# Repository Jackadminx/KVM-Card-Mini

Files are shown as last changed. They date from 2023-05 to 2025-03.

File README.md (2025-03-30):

# KVM-Card-Mini

⌨️🖥️🖱️

Simple KVM Console to USB 

[ENGLISH Version](https://github.com/Jackadminx/KVM-Card-Mini/blob/main/README-en.md)

一款即插即用的 KVM （Keyboard Video Mouse）设备控制卡

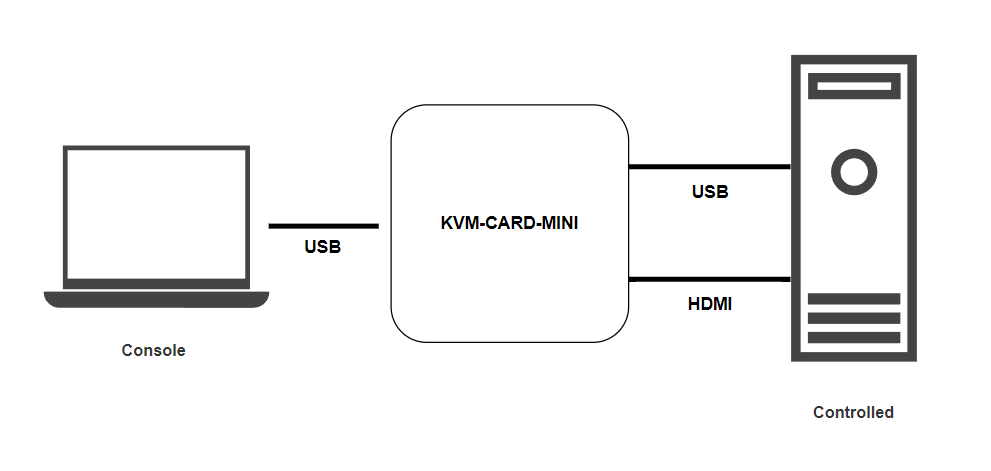
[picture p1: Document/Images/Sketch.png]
Sketch


## 功能特点

- HID 协议传输，免驱动，支持USB FS传输速度
- 支持 BIOS 键盘控制
- 上位机程序兼容非板载视频采集卡
- 板载 USB HUB 芯片，减少接口数量
- MCU 双 USB Device 控制器，降低传输延迟
- 板载蓝牙天线、调试接口，可用于MCU开发
- USB 设备主从切换

[演示视频](https://www.bilibili.com/video/BV1Mh4y1o7ya)

## 硬件分析

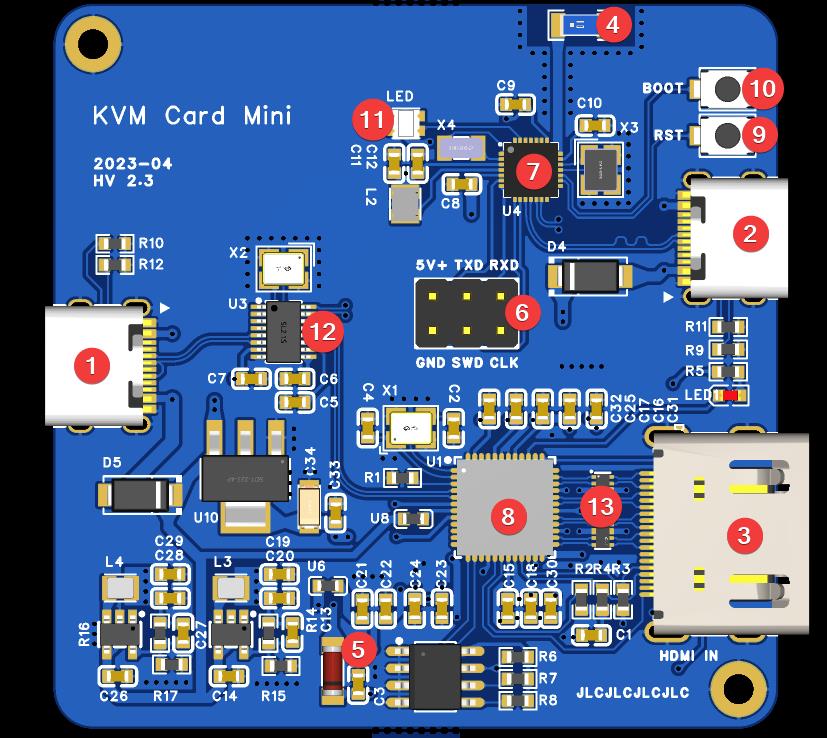
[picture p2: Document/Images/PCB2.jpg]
PCB


1. **（控制端）USB Host Type-C 接口，连接至上位机**
2. **（被控端）USB Host Type-C 接口，连接至被控端，控制键盘鼠标**
3. **（被控端）标准 HDMI 视频输入接口，连接至被控端视频输出**
4. 蓝牙陶瓷天线（~能用但不完全能用，没有做阻抗匹配~；可选安装元器件）
5. EEPROM 支持烧录夹烧录
6. CH582F 调试接口，只支持 WCH-Link （可选安装元器件）
7. CH582F 
8. MS2109
9. CH582F 复位按钮
10. CH582F USB 烧录选择按钮
11. WS2812B（可选安装元器件）
12. SL2.1s
13. HDMI ESD防护（可选安装元器件）

## 上位机（控制端）

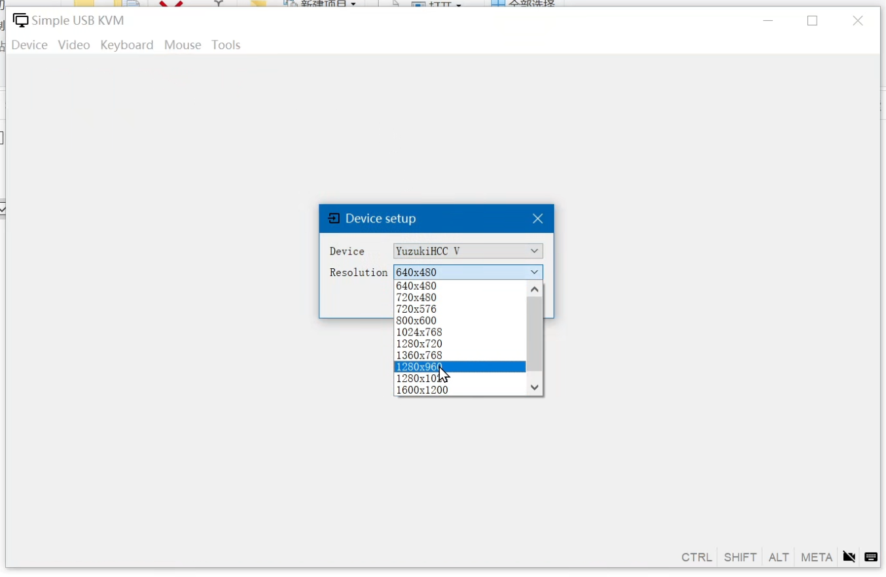
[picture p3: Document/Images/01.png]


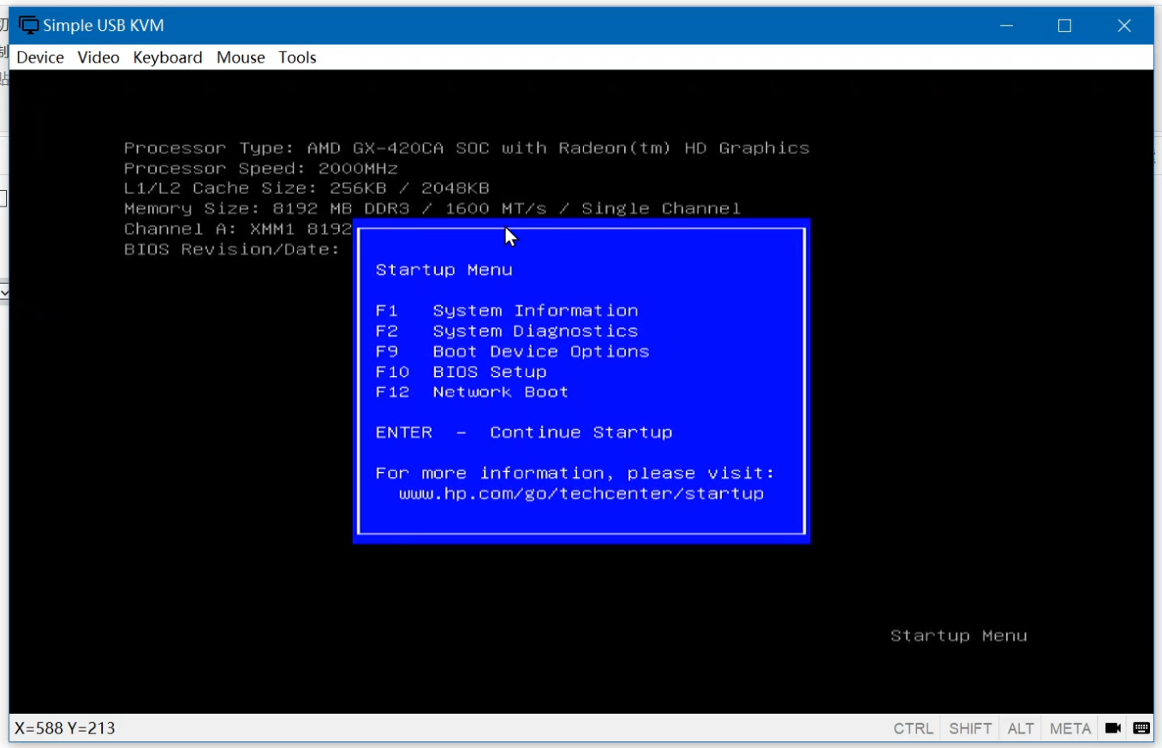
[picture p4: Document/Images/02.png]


- 屏幕显示：支持视频输入选择、切换输出分辨率
- 键盘控制：支持自定义快捷键、6键无冲突
- 鼠标控制：绝对鼠标模式
- 键盘指示灯显示
- 重置 MCU 和重置 HID 连接功能
- 批量文本输入
- ~~全键无冲突~~ 
- 最大 1000hz 鼠标回报率
- 屏幕截图

开发中：
- USB 切换选择、自动切换
- USB HID 电源键功能

### Web Version(alpha)
[演示地址](https://webclient.0x8991.com/)

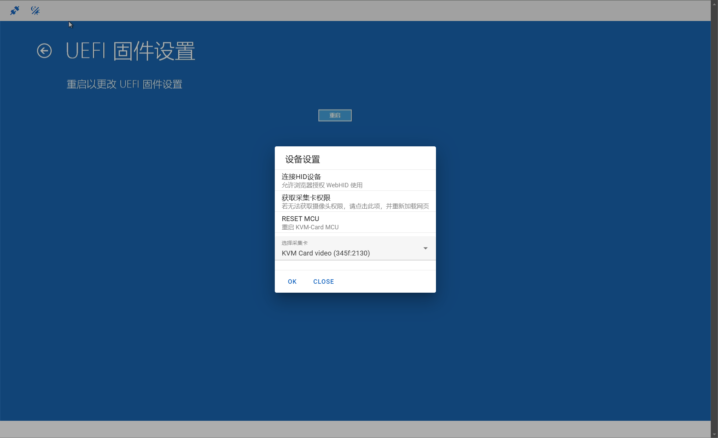
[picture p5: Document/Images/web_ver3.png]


## 固件刷入

### CH582

按住 BOOT 键同时使用USB数据线连接至电脑，然后使用 [WCHISPTool](https://www.wch.cn/downloads/WCHISPTool_Setup_exe.html) 刷入固件
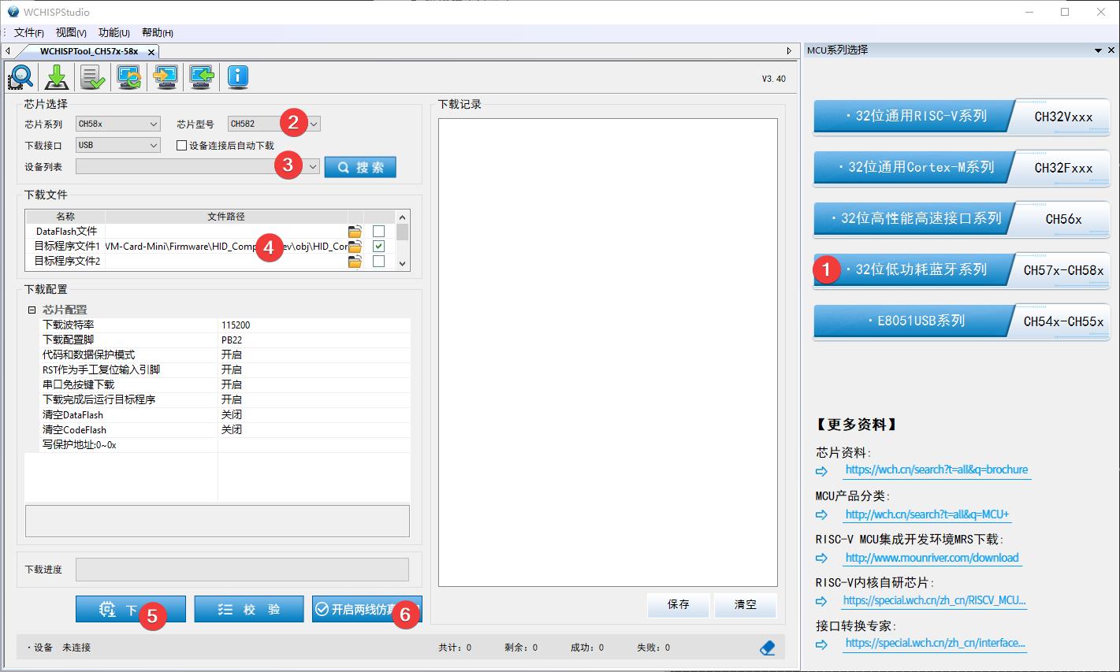
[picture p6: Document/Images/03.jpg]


若不使用调试接口，则不需要开启两线仿真接口，即步骤6

### MS2109

配套的AT24C16 EEPROM可以直接买套片，或者用EEPROM编程器烧录。
可以使用烧录夹在板子断电状态进行烧录。

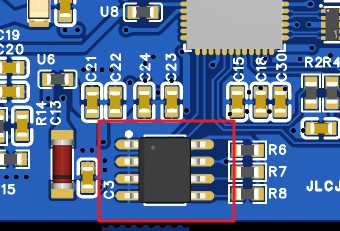
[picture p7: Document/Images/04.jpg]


MS2109的固件来自 [Yuzuki HCC HDMI](https://oshwhub.com/gloomyghost/yuzuki-hcc) 项目，可通过HEX文件编辑器编辑固件实现修改设备名。

## 实物图

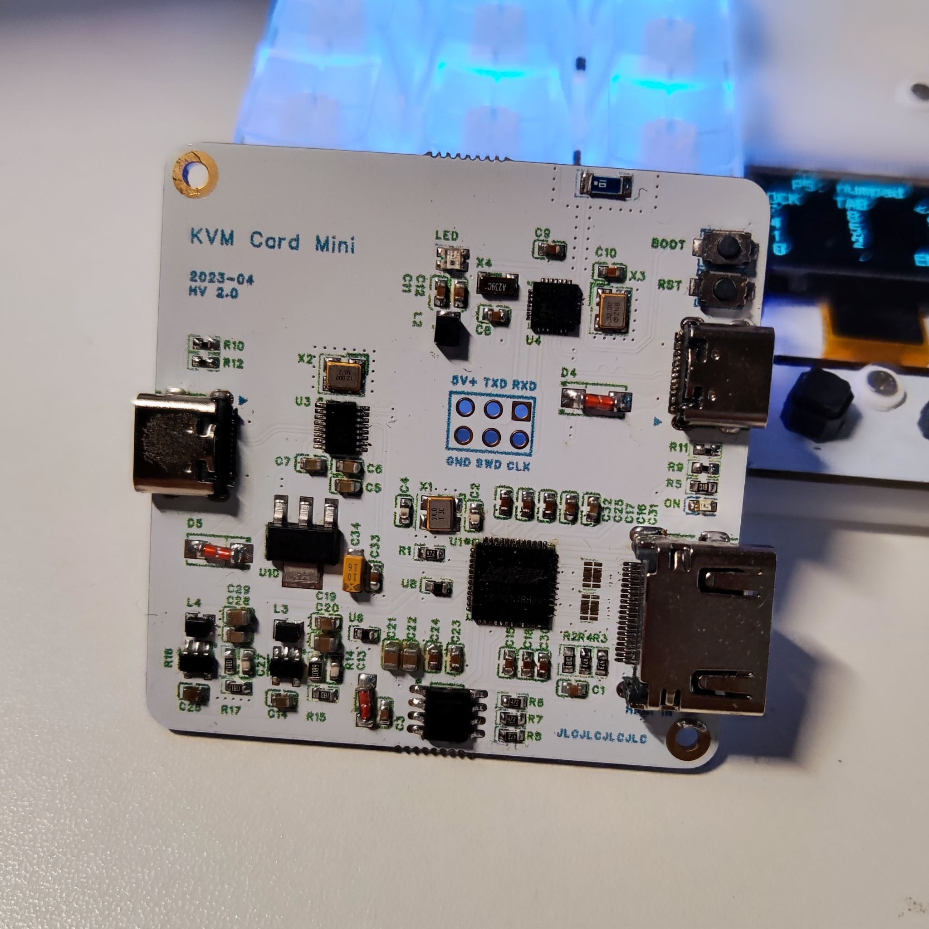
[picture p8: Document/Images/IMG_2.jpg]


HV2.0

*嘉立创彩色丝印版本

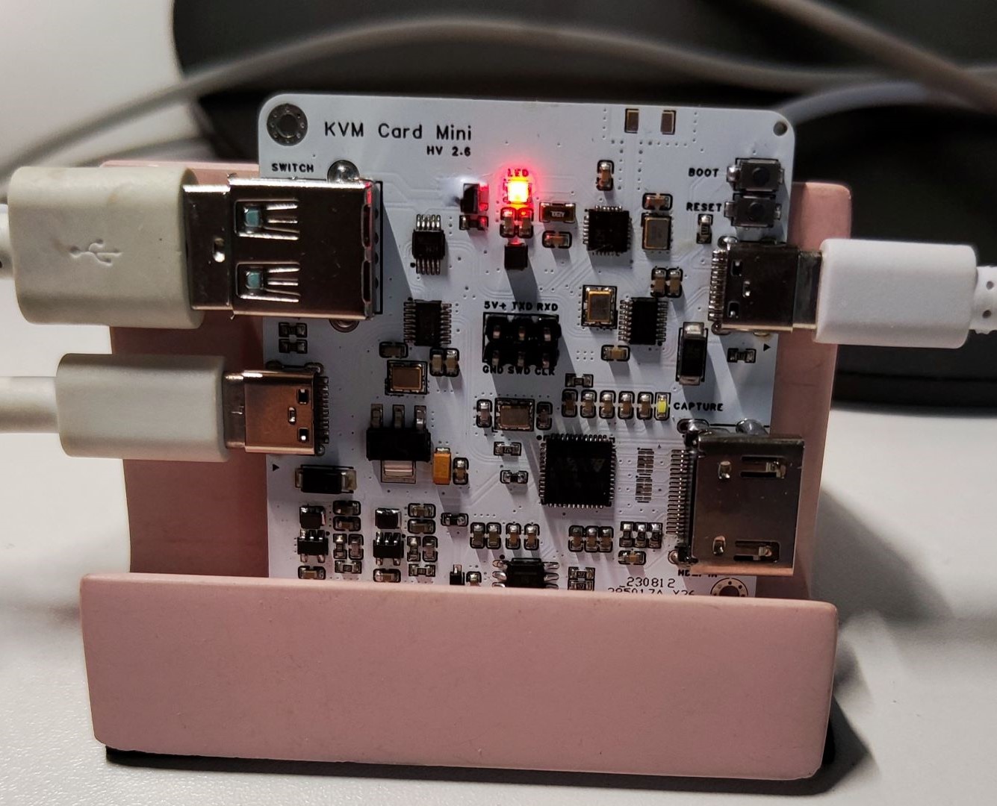
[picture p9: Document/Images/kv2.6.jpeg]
kv2.6


HV2.6

添加USB切换接口

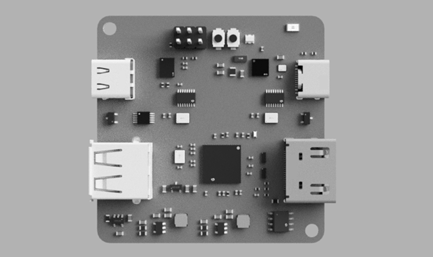
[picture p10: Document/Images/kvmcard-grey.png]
kv3.2


HV3.2 (开发中)

## 感谢

https://oshwhub.com/gloomyghost/yuzuki-hcc

https://materialdesignicons.com/icon/

https://www.riverbankcomputing.com/software/pyqt/

https://github.com/apmorton/pyhidapi

https://www.mounriver.com/

https://pro.lceda.cn/editor

和其他开源或免费项目

感谢 @ElluIFX 同学的制作的增强型客户端：
https://github.com/ElluIFX/KVM-Card-Mini-PySide6

## [License](https://github.com/Jackadminx/KVM-Card-Mini/blob/main/LICENSE)

The MIT License (MIT)

Copyright (c) 2023-2024 Jancgk

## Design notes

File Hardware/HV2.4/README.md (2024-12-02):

Edit Schematics and PCBs Online with EasyEDA Professional Edition

https://oshwhub.com/jancgk/kvm-card-mini

`BOM_Board1_Schematic1_2023-05-21.xlsx` BOM

`Gerber_PCB1_陶瓷天线_2023-05-21.zip` Gerber

`ProProject_KVM-Card mini_2023-05-21.zip` EasyEDA Professional Project Archive

`SCH_Schematic1_2023-05-21.pdf` Schematic

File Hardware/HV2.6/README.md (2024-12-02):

Edit Schematics and PCBs Online with EasyEDA Professional Edition

https://oshwhub.com/jancgk/kvm-card-mini-plus

ProProject_KVM-Card-Mini-HV2.6_2023-09-18.epro 

EasyEDA Professional Project Archive

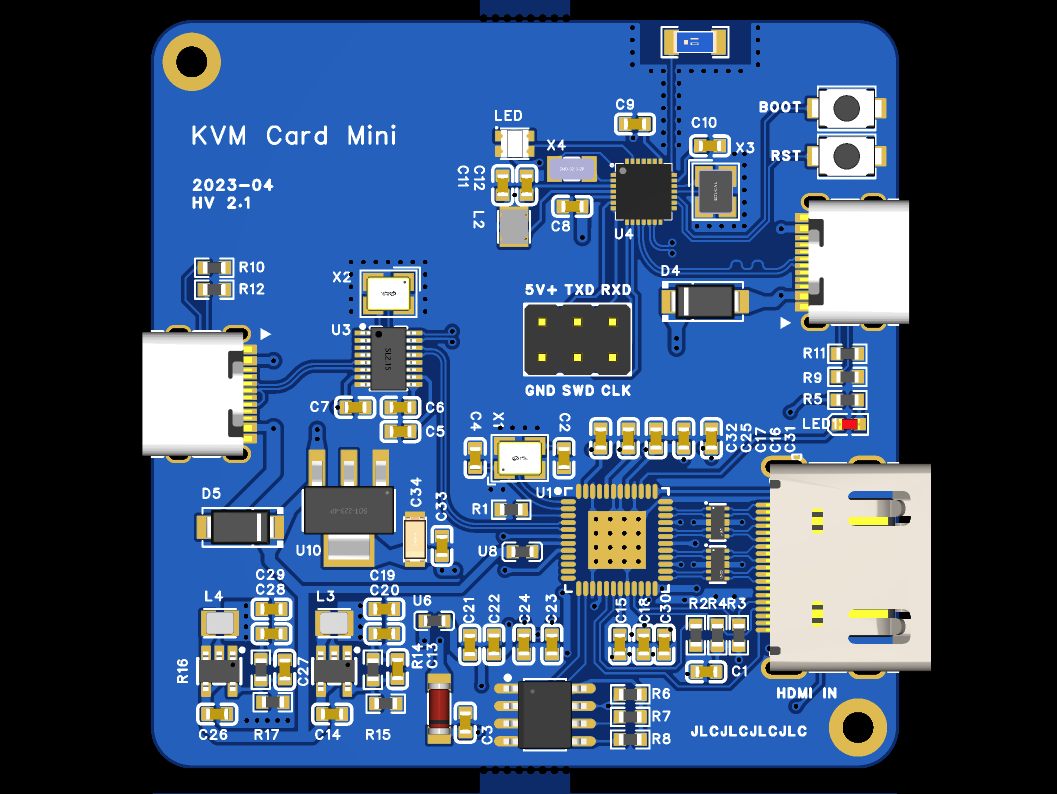
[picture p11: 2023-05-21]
Document/Images/PCB.png

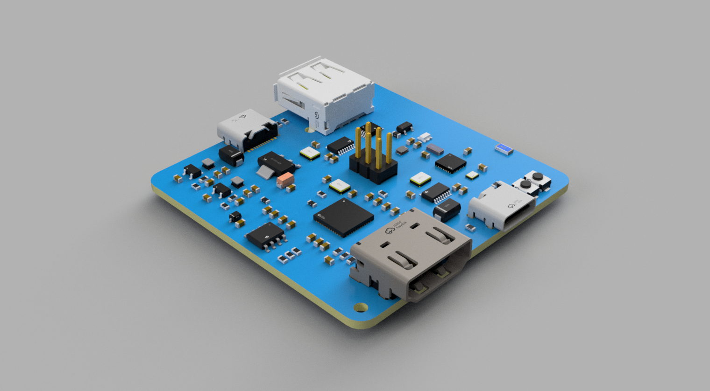
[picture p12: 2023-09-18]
Document/Images/hv2.6-1.png

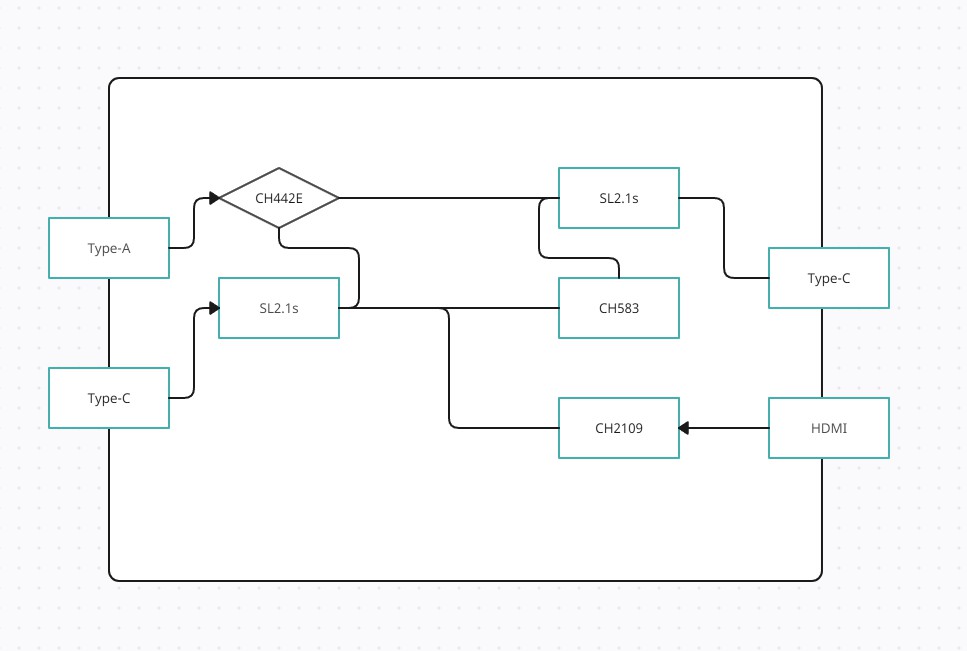
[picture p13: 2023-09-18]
Document/Images/OqkMmGFWqzc19HXRmTqjMmWJ7LFyIBar70Tsb4bh.jpg

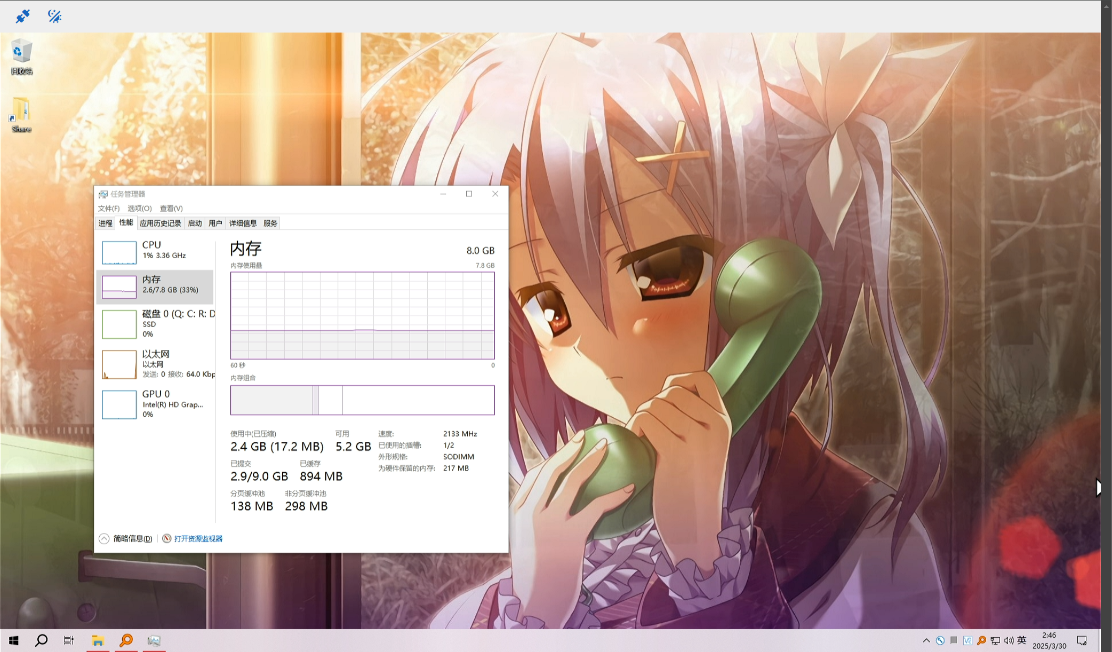
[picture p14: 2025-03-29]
Document/Images/web_ver.png

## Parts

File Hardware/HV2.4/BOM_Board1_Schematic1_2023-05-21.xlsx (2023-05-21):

No. | Quantity | Comment | Designator | Footprint | Value | Manufacturer Part | Manufacturer | Supplier Part | Supplier | LCSC Part Name | Locking Feature | Datasheet | Description
1 | 14 | 100nF | C1,C3,C9,C15,C16,C17,C18,C23,C24,C25,C30,C31,C32,C33 | C0603 | 100nF |  |  |  |  |  |  |  | 容值:100nF;精度:±10%;额定电压:50V;温度系数:X7R;
2 | 4 | 20pf | C2,C4,C13,C27 | C0603 | 20pf |  |  |  |  |  |  |  | 容值:100nF;精度:±10%;额定电压:50V;温度系数:X7R;
3 | 3 | 10uF | C5,C6,C7 | C0603 | 10uF | CL10A106MA8NRNC | SAMSUNG(三星) | C96446 | LCSC | 10uF ±20% 25V |  | https://atta.szlcsc.com/upload/public/pdf/source/20170325/1490427913016.pdf | 容值:10uF;精度:±20%;额定电压:25V;温度系数:X5R;
4 | 4 | 2.2uf | C8,C10,C11,C12 | C0603 | 2.2uf |  |  |  |  |  |  |  | 容值:100nF;精度:±10%;额定电压:50V;温度系数:X7R;
5 | 4 | 10uf | C14,C19,C26,C28 | C0603 | 10uf |  |  |  |  |  |  |  | 容值:100nF;精度:±10%;额定电压:50V;温度系数:X7R;
6 | 4 | 22uf | C20,C21,C22,C29 | C0603 | 22uf |  |  |  |  |  |  |  | 容值:100nF;精度:±10%;额定电压:50V;温度系数:X7R;
7 | 1 | 10uF | C34 | CASE-A_3216 | 10uF | CA45-A-6.3V-10uF-K | CEC(振华新云) | C128255 | LCSC | 10uF ±10% 6.3V |  | https://atta.szlcsc.com/upload/public/pdf/source/20180125/C128255_15168614678451301481.pdf | 容值:10uF;精度:±10%;额定电压:6.3V;等效串联电阻:8Ω@100kHz;
8 | 2 | RClamp0524PATCT | D1,D2 | SLP2510P8_L2.5-W1.0-P0.50-BL |  | RClamp0524PATCT | SEMTECH | C40960 | LCSC | RClamp0524PATCT |  | https://atta.szlcsc.com/upload/public/pdf/source/20150124/1457707260739.pdf | VBR=6V， Vc=15V ，Ipp=5A
9 | 1 | LL4148 | D3 | LL-34_L3.5-W1.5-R-RD |  | LL4148 | ST(先科) |  | LCSC | 75V 200mA 4ns |  | https://atta.szlcsc.com/upload/public/pdf/source/20121108/1457706554347.pdf | 二极管配置:-;功率:500mW;直流反向耐压(Vr):75V;平均整流电流(Io):200mA;正向压降(Vf):1V@10mA;反向电流(Ir):5A@75V;反向恢复时间(trr):4ns;工作温度:+175@(Tj);
10 | 2 | 1N4007 | D4,D5 | SMA_L4.3-W2.5-LS5.0-RD |  | 1N4007 | TWGMC(台湾迪嘉) | C727081 | LCSC | 1kV 1A 1.1V@1A |  | https://atta.szlcsc.com/upload/public/pdf/source/20200828/C727079_3A05254382567072883400655AE0ED46.pdf | 二极管配置:独立式;直流反向耐压(Vr):1kV;平均整流电流(Io):1A;正向压降(Vf):1.1V@1A;反向电流(Ir):5uA@1kV;
11 | 1 | 210-72-03GB01 | H1 | HDR-TH_6P-P2.54-V-R2-C3-S2.54_A2541WV-2X3P |  | 210-72-03GB01 | PINREX(频锐科技) | C402781 | LCSC | 2.54mm 2x3P 直插 方针 |  | https://atta.szlcsc.com/upload/public/pdf/source/20190710/C402781_43A1999CD2F74066250BE88CD0917A4C.pdf | 排数:双排;总PIN位数:6;间距:2.54mm;插针结构:2x3P;行距:2.54mm;安装类型:直插;圆针/方针:方针;额定电流:-;额定电压:-;配合针长度:6.1mm;塑高:2.5mm;端接针长度:3mm;触头材质:黄铜;触头镀层:-;工作温度范围:-40℃~+105℃;颜色:黑色;
12 | 1 | HDMI-019S | HDMI1 | HDMI-SMD_HDMI-019S |  | HDMI-019S | SOFNG(硕方) | C111617 | LCSC | HDMI 母 P数:19 |  | https://atta.szlcsc.com/upload/public/pdf/source/20200911/C111617_84DD1BD35B9EB8A28224A63520745D0A.pdf | 连接器类型:HDMI;公母:母;总PIN位数:19;排数:-;安装方式:卧贴;额定电流:500mA;工作温度范围:-25~+75;
13 | 1 | RFECA3216060A1T | L1 | ANT-SMD_L3.1-W1.6 |  | RFECA3216060A1T | Walsin(华新科) | C127620 | LCSC | RFECA3216060A1T |  | https://atta.szlcsc.com/upload/public/pdf/source/20180326/C127620_3C564CCA307EE04222EAFCE04B7FD99A.pdf | 2.4 GHz 陶瓷天线
14 | 1 | 22uH | L2 | IND-SMD_L2.5-W2.0_FNR252012S | 22uH | FNR252012S220MT | cjiang(长江微电) | C167709 | LCSC | 22uH ±20% 0.38A |  | https://atta.szlcsc.com/upload/public/pdf/source/20190327/C167709_4833153A6C5859FE5472BBE6A86A035C.pdf | 直流电阻(DCR):1.976Ω;精度:±20%;额定电流:380mA;电感值:22uH;
15 | 2 | 2.2uH | L3,L4 | IND-SMD_L2.0-W1.6 | 2.2uH | CKCS201610-2.2uH/M | CENKER(岑科) | C354533 | LCSC | 2.2uH ±20% 1.1A 264mΩ |  | https://atta.szlcsc.com/upload/public/pdf/source/20190315/C354533_59121B22FE01331804674A67C9C7C2C4.pdf | 电感值:2.2uH;精度:±20%;额定电流:1.1A;
16 | 1 |  | LED1 | LED_0603
17 | 1 | WS2812B-2020 | LED2 | LED-SMD_4P-L2.0-W2.0-TL_WS2812B-2020 |  | WS2812B-2020 | worldsemi | C965555 | LCSC | RGB三色 470.4nm 515.6nm 622.5nm （注意防潮，请查阅规格书中对应具体内容） |  | https://atta.szlcsc.com/upload/public/pdf/source/20201203/C965555_5C919C4B6231E6ADE06011FB0D94282B.pdf | 发光颜色:RGB三色;二极管配置:-;透镜颜色:-;主波长:470.4nm；622.5nm；515.6nm;峰值波长:-;色温:-;测试电流:12mA;功率:-;发光角度:-;安装方式:-;工作温度:-;
18 | 4 | 4k7 | R1,R6,R7,R8 | R0603 | 4k7
19 | 2 | 1k | R2,R5 | R0603 | 1k
20 | 2 | 47k | R3,R4 | R0603 | 47k
21 | 4 | 5.1K | R9,R10,R11,R12 | R0603 | 5.1K
22 | 1 | 680K | R14 | R0603 | 680K
23 | 3 | 150K | R15,R16,R17 | R0603 | 150K
24 | 1 | TS342A2P-WZ | SW1 | SW-SMD_L4.0-W2.9-LS5.0 | BOOT | TS342A2P-WZ | SHOU HAN(首韩) |  | LCSC | 轻触开关 3*4*2 两脚小龟不带柱 250gf 黑色塑胶按钮 |  | https://atta.szlcsc.com/upload/public/pdf/source/20200519/C557591_B3A5A21584733303F06306F18577DA8B.pdf | 触点电流:50mA;额定电压(DC):12V;绝缘电阻:100MΩ;电路结构:单刀单掷;安装方式:立贴;按钮形状:圆形按钮;按钮/盖帽颜色:黑色;机械寿命:30000;工作温度:-25℃~+70℃;引脚样式:SMD接片;开关长度:3.95mm;开关宽度:2.9mm;开关高度:2mm;带支架:否;
25 | 1 | TS342A2P-WZ | SW2 | SW-SMD_L4.0-W2.9-LS5.0 | RST | TS342A2P-WZ | SHOU HAN(首韩) |  | LCSC | 轻触开关 3*4*2 两脚小龟不带柱 250gf 黑色塑胶按钮 |  | https://atta.szlcsc.com/upload/public/pdf/source/20200519/C557591_B3A5A21584733303F06306F18577DA8B.pdf | 触点电流:50mA;额定电压(DC):12V;绝缘电阻:100MΩ;电路结构:单刀单掷;安装方式:立贴;按钮形状:圆形按钮;按钮/盖帽颜色:黑色;机械寿命:30000;工作温度:-25℃~+70℃;引脚样式:SMD接片;开关长度:3.95mm;开关宽度:2.9mm;开关高度:2mm;带支架:否;
26 | 1 | MS2109 | U1 | QFN-48_L7.0-W7.0-P0.50-TL-EP4.1 |  |  |  |  |  |  |  | 无
27 | 1 | AT24C16M/TR | U2 | SOP-8_L4.9-W3.9-P1.27-LS6.0-BL |  | AT24C16M/TR | HGSEMI(华冠) | C356701 | LCSC | AT24C16M/TR |  | https://atta.szlcsc.com/upload/public/pdf/source/20220714/5A9938374CA1B0C07A427C61968786F5.pdf
28 | 1 | SL2.1s | U3 | SSOP-16_L4.6-W2.6-P0.53-LS4.0-BL |  | SL2.1s | CoreChips(和芯润德) | C2684433 | LCSC | SL2.1s |  | https://atta.szlcsc.com/upload/public/pdf/source/20210326/C2684433_0308B0C984AD3FC6CBDA43F1CDB06B3F.pdf | 类型:-;协议类别:-;驱动器/接收器数:-;数据速率:-;
29 | 1 | CH582F | U4 | QFN-28_L4.0-W4.0-P0.40-BL-EP2.8 |  | CH582F | WCH(南京沁恒) | C3001175 | LCSC | CH582F |  | https://atta.szlcsc.com/upload/public/pdf/source/20220425/D81D4537E275CD6C7C3E77BC95B144F3.pdf
30 | 2 | MT3520B | U5,U7 | SOT-23-5_L3.0-W1.7-P0.95-LS2.8-BR |  | MT3520B | 西安航天民芯 | C2684933 | LCSC
31 | 2 | BLM18PG121SN1D | U6,U8 | L0603 |  | BLM18PG121SN1D | muRata(村田) | C14709 | LCSC | 120Ω@100MHz ±25% |  | https://atta.szlcsc.com/upload/public/pdf/source/20130704/1457706621134.pdf | 标称阻抗@测试频率:120Ω@100MHz;误差:±25%;直流电阻(RDC):50mΩ;额定电流:2A;电路数:1;
32 | 1 | AMS1117-3.3 | U10 | SOT-223-3_L6.5-W3.4-P2.30-LS7.0-BR |  | AMS1117-3.3 | AMS | C6186 | LCSC | 输出3.3V 1A |  | https://atta.szlcsc.com/upload/public/pdf/source/20180727/C6186_7A095716F0823C02F1997A905E26C086.pdf | 输出类型:固定;输出极性:正;最大输入电压:-;输出电压:3.3V;输出电流:1A;电源纹波抑制比(PSRR):72dB@(120Hz);
33 | 2 | TYPE-C-31-M-12 | USBC1,USBC2 | USB-C_SMD-TYPE-C-31-M-12 |  | TYPE-C-31-M-12 | 韩国韩荣 | C165948 | LCSC | Type-C 母座 |  | https://atta.szlcsc.com/upload/public/pdf/source/20220525/466408E853115E789EDB0DDC29077C05.pdf | 连接器类型:Type-C;标准:-;公母:母座;触点数量:16;端口数量:1;安装方式:-;额定电流 - 电源:5A;触头材质:-;触头镀层:-;工作温度范围:-;焊接温度(最大值):-;
34 | 1 | - | X1 | OSC-SMD_4P-L3.2-W2.5-BL | - | SX32Y024000BC1T | TKD(泰晶) | C271629 | LCSC | 3225 24M 12PF 10ppm -20 -75℃ |  | https://atta.szlcsc.com/upload/public/pdf/source/20180829/C271629_CA81D930E8823EB83EE4F79A596DDEFE.pdf | 频率:-;负载电容:-;
35 | 1 | 12MHz | X2 | CRYSTAL-SMD_4P-L3.2-W2.5-BL | 12MHz | Q22FA23V0041800 | EPSON(爱普生) | C91749 | LCSC | 12MHz ±20ppm 18pF |  | https://atta.szlcsc.com/upload/public/pdf/source/20180607/C91749_498DD7D6A132F22CC899BC8E162EB8BB.pdf | 晶振类型:贴片无源晶振;频率:12MHz;频率公差:±20ppm;频率稳定度:-;负载电容:18pF;等效串联电阻(ESR):100Ω;工作温度:-40~+85;
36 | 1 | 32MHz | X3 | CRYSTAL-SMD_4P-L3.2-W2.5-BL | 32MHz | TZ0375A | TST(嘉硕) | C498198 | LCSC | 32MHz 12pF |  | https://atta.szlcsc.com/upload/public/pdf/source/20200416/C498198_A8C7D507DCA02A785634ACE6A3F57BEC.pdf | 频率:32MHz;频率稳定度:±10ppm;负载电容:12pF;
37 | 1 | 32.768kHz | X4 | FC-135R_L3.2-W1.5 | 32.768kHz | Q13FC1350000400 | EPSON(爱普生) | C32346 | LCSC | 32.768kHz ±20ppm 12.5pF |  | https://atta.szlcsc.com/upload/public/pdf/source/20190108/C32346_746D6B07EAF90824457A96480007685F.pdf | 晶振类型:贴片无源晶振;频率:32.768kHz;频率公差:±20ppm;负载电容:12.5pF;等效串联电阻(ESR):70kΩ;工作温度:-40℃~+85℃;

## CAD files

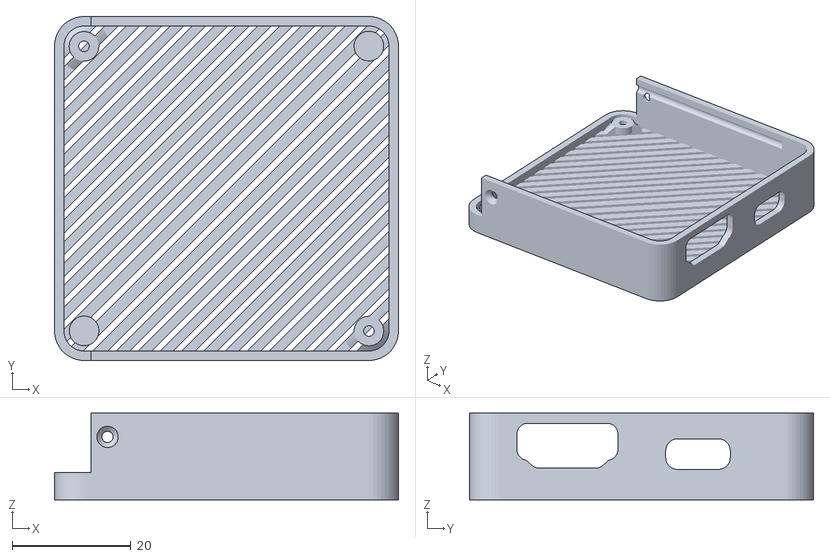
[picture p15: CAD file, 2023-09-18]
Hardware/HV2.4/Shell/Shell_Down_HV2.4.stl
58.0 x 58.0 x 14.6

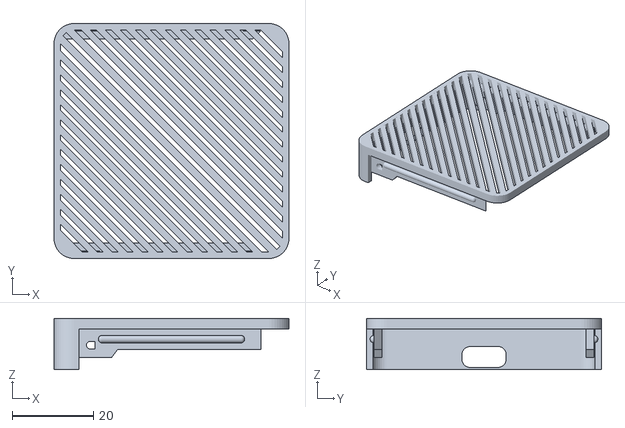
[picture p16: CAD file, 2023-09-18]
Hardware/HV2.4/Shell/Shell_Up_HV2.4.stl
58.0 x 58.0 x 12.6

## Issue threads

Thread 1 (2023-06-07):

为这个项目适配了一下open-ip-kvm

ElluIFX, 2023-06-07:
https://github.com/ElluIFX/open-ip-kvm
多谢大佬的硬件实现

Jackadminx, 2023-06-11:
谢谢，感谢你对本项目的适配

liustar1989, 2023-08-12:
>

大佬请教一下，使用n1在armbian中部署了µStreamer、Node.js、ElluIFX/open-ip-kvm，但是执行npm run start提示报错，单独执行./ustreamer是可以运行ustreamer，能不能帮忙看下是什么问题啊？

root@armbian:~/open-ip-kvm# npm run start

> open-ip-kvm@1.0.0 start /root/open-ip-kvm
> sudo node server/index.js

TypeError: cannot open device with vendor id 0x413d and product id 0x2107
    at new HID (/root/open-ip-kvm/node_modules/node-hid/nodehid.js:49:17)
    at new HIDController (/root/open-ip-kvm/server/hid.js:38:23)
    at start (/root/open-ip-kvm/server/index.js:20:15)
    at Object.<anonymous> (/root/open-ip-kvm/server/index.js:100:1)
    at Module._compile (internal/modules/cjs/loader.js:1068:30)
    at Object.Module._extensions..js (internal/modules/cjs/loader.js:1097:10)
    at Module.load (internal/modules/cjs/loader.js:933:32)
    at Function.Module._load (internal/modules/cjs/loader.js:774:14)
    at Function.executeUserEntryPoint [as runMain] (internal/modules/run_main.js:72:12)
    at internal/main/run_main_module.js:17:47
npm ERR! code ELIFECYCLE
npm ERR! errno 1
npm ERR! open-ip-kvm@1.0.0 start: `sudo node server/index.js`
npm ERR! Exit status 1
npm ERR!
npm ERR! Failed at the open-ip-kvm@1.0.0 start script.
npm ERR! This is probably not a problem with npm. There is likely additional logging output above.

npm ERR! A complete log of this run can be found in:
npm ERR!     /root/.npm/_logs/2023-08-12T00_57_28_225Z-debug.log

ElluIFX, 2023-09-18:
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

报错不是很显然么，没找到设定的hid设备，可以lsusb看看是不是真的接入了

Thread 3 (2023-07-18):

用ch9329会不会比CH582F更合适？

MasterOfStar, 2023-07-18:

Jackadminx, 2023-07-18:
ch9329可以实现模拟键盘和鼠标功能，但是不够灵活，不支持自定义开发

MasterOfStar, 2023-07-18:
> ch9329可以实现模拟键盘和鼠标功能，但是不够灵活，不支持自定义开发

也是 9329除了kvm模拟键鼠什么都做不了，582F应该还可以再接一路继电器开机(

Jackadminx, 2023-07-18:
ch9329通用性强，而且有很多适配方案。硬件上需要接一颗串口芯片，另外需要安装驱动，ch582只要一颗芯片就能搞定，使用HID协议可以免驱动。
本项目设计初衷是设备快速安装维护、桌面设备调试，免去键鼠显示器，节省桌面空间。

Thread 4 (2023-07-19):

很需要，求众筹量产

CodeIntegrity, 2023-07-19:
如题，手残自己不会做啊，运维人太难了

hexesdesu, 2023-07-24:
同求

Jackadminx, 2023-07-25:
@hexesdesu @CodeIntegrity 交流群 894345556

binnehot, 2025-05-01:
@hexesdesu
@CodeIntegrity
@luodaoyi

有公司已经做成了产品 贝锐向日葵 Q0.5， 用WCHISPTool刷入1.3固件，可以用 @Jackadminx 大佬或者@ElluIFX 大佬的软件。https://webclient.0x8991.com/ 这个地址也能用

luodaoyi, 2025-05-01:
> WCHISPTool

可以不用向日葵的账号啥的码？ 就本地控制还得注册账号

ElluIFX, 2025-05-01:
> [@hexesdesu](https://github.com/hexesdesu) [@CodeIntegrity](https://github.com/CodeIntegrity) [@luodaoyi](https://github.com/luodaoyi)
>
> 有公司已经做成了产品 贝锐向日葵 Q0.5， 用WCHISPTool刷入1.3固件，可以用 [@Jackadminx](https://github.com/Jackadminx) 大佬或者[@ElluIFX](https://github.com/ElluIFX) 大佬的软件。[webclient.0x8991.com](https://webclient.0x8991.com/) 这个地址也能用

还有这事，长见识了。很好奇是巧合还是开源转化，毕竟如果恰巧用的一样的芯片，pinout选择一致也有可能。

binnehot, 2025-05-01:
> > WCHISPTool
>
> 可以不用向日葵的账号啥的码？ 就本地控制还得注册账号

刷了MCU固件之后，就完全和这个开源项目一样了。 想回去用向日葵账号都用不了。

binnehot, 2025-05-01:
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

https://github.com/binnehot/KVM_over_USB_Q05
看一下PCB板子，就是 @Jackadminx 大佬的HV2.6，把MS2109换成了MS2131，PCB重新走线。
开源项目转产品，不要把刷固件的路堵住就很好，这样把大家折腾的门槛降低了，好事。

luodaoyi, 2025-05-01:
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

那爽了

ElluIFX, 2025-05-03:
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

挺好的，回头我在readme引用一下你的教程作为低成本硬件方案了，谢谢

luodaoyi, 2025-05-05:
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

请问你的向日葵是咋拆开额？ 我看了一圈没看到螺丝啊 难道就是撬开的？

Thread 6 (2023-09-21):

改进了一下上位机， 加了很多功能

ElluIFX, 2023-09-21:
https://github.com/ElluIFX/KVM-Card-Mini-PySide6
因为代码改动实在太多就不pr了，就当是个社区特别版（
作者的card很好用，感谢
欢迎提issue，我会加功能的

ElluIFX, 2023-09-21:
另外提个小建议，hid端点描述符最后一个字节是报告间隔，可以把u2的报告间隔也设成1来获得更低的延时，防止丢键（我不理解为什么u1是1ms，u2却设成10ms）
另外报告可以在中断里直接转发，效率最高
如图：
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

Jackadminx, 2023-09-22:
感谢大佬对本项目的大力支持，上位机功能很全面，很好用

Jackadminx, 2023-09-22:
感谢大佬对firmware的源码的建议，后续会进行优化

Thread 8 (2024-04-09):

HDMI视频采集性能如何提高?

vincentzz, 2024-04-09:
大佬你好，我在用v2.6版本硬件，原版Client以及增强Client里最多都只能选1080P，而且目测帧率远远达不到60，色深不足，同时MS2109发热严重。

我被控机MacBook输出信号是2K 60hz，主控机Windows用的4K 144hz屏幕，所以从主控机上看到的画面就比较难以接受。
我想请问是散热局限了性能吗？还是被芯片本身的性能限制了？

如果想高质量采集视频，可以通过改固件外加风扇实现吗？还是说需要更强的芯片才行？

vincentzz, 2024-04-12:
明白了，多谢大佬指点

Closed 2024-04-12.

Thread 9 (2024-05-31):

HDMI工作，键盘鼠标不工作

vincentzz, 2024-05-31:
硬件版本：v2.6
Win Client版本：V1.2
操作系统：win10

现象：
1. HDMI功能OK， 键盘鼠标操作无法同步到被控机。开debug模式，可以看到win client能捕捉到键鼠操作，但被控机没有收到。
2. 板子上两个LED亮红灯。
3. 启动后load完本地HID设备后，win client很卡。按板子上的reset后，卡顿消失，reload键鼠后，又很卡。

Jackadminx, 2024-05-31:
请确认双USB接口是否工作正常，可以按住boot键并连接电脑，使用WCHISPTool检查双USB是否能够识别。

vincentzz, 2024-06-03:
两个USB都可以正常识别。

Jackadminx, 2024-06-03:
试试被控机运行上位机反向控制主控机是否有这个问题

vincentzz, 2024-06-04:
换用另一台win11当主控机，鼠标和键盘就可以使用。。。
我怀疑是跟这台电脑上的一些软件或者外设冲突了，但从log里没能找到太多帮助排查的信息

···
status Variable not initialized
{'path': b'\\\\?\\HID#VID_046D&PID_C539&MI_00#8&808363a&0&0000#{4d1e55b2-f16f-11cf-88cb-001111000030}\\KBD', 'vendor_id': 1133, 'product_id': 50489, 'serial_number': '', 'release_number': 14596, 'manufacturer_string': 'Logitech', 'product_string': 'USB Receiver', 'usage_page': 1, 'usage': 6, 'interface_number': 0}
{'path': b'\\\\?\\HID#VID_048D&PID_5702&Col01#7&38401973&1&0000#{4d1e55b2-f16f-11cf-88cb-001111000030}', 'vendor_id': 1165, 'product_id': 22274, 'serial_number': '', 'release_number': 1, 'manufacturer_string': 'ITE Tech. Inc.', 'product_string': 'ITE Device', 'usage_page': 65417, 'usage': 16, 'interface_number': -1}
{'path': b'\\\\?\\HID#VID_048D&PID_5702&Col02#7&38401973&1&0001#{4d1e55b2-f16f-11cf-88cb-001111000030}', 'vendor_id': 1165, 'product_id': 22274, 'serial_number': '', 'release_number': 1, 'manufacturer_string': 'ITE Tech. Inc.', 'product_string': 'ITE Device', 'usage_page': 65417, 'usage': 204, 'interface_number': -1}
{'path': b'\\\\?\\HID#VID_FEED&PID_0000&MI_00#8&1c134abe&0&0000#{4d1e55b2-f16f-11cf-88cb-001111000030}\\KBD', 'vendor_id': 65261, 'product_id': 0, 'serial_number': '', 'release_number': 1, 'manufacturer_string': 'Vincent Zhao Zhang', 'product_string': 'zz64', 'usage_page': 1, 'usage': 6, 'interface_number': 0}
{'path': b'\\\\?\\HID#VID_FEED&PID_0000&MI_01&Col01#8&44fbe79&0&0000#{4d1e55b2-f16f-11cf-88cb-001111000030}', 'vendor_id': 65261, 'product_id': 0, 'serial_number': '', 'release_number': 1, 'manufacturer_string': 'Vincent Zhao Zhang', 'product_string': 'zz64', 'usage_page': 1, 'usage': 2, 'interface_number': 1}
{'path': b'\\\\?\\HID#VID_413D&PID_2107#8&2cadb3f0&0&0000#{4d1e55b2-f16f-11cf-88cb-001111000030}', 'vendor_id': 16701, 'product_id': 8455, 'serial_number': '', 'release_number': 256, 'manufacturer_string': 'Moyu at work Technology', 'product_string': 'KVM Card Mini', 'usage_page': 65280, 'usage': 1, 'interface_number': -1}
{'path': b'\\\\?\\HID#VID_FEED&PID_0000&MI_01&Col02#8&44fbe79&0&0001#{4d1e55b2-f16f-11cf-88cb-001111000030}', 'vendor_id': 65261, 'product_id': 0, 'serial_number': '', 'release_number': 1, 'manufacturer_string': 'Vincent Zhao Zhang', 'product_string': 'zz64', 'usage_page': 1, 'usage': 128, 'interface_number': 1}
{'path': b'\\\\?\\HID#VID_534D&PID_2109&MI_04#9&12dff07&0&0000#{4d1e55b2-f16f-11cf-88cb-001111000030}', 'vendor_id': 21325, 'product_id': 8457, 'serial_number': '', 'release_number': 8448, 'manufacturer_string': 'MACROSILICON', 'product_string': 'USB Video', 'usage_page': 65280, 'usage': 1, 'interface_number': 4}
{'path': b'\\\\?\\HID#VID_046D&PID_C539&MI_01&Col01#8&2bdf73fc&0&0000#{4d1e55b2-f16f-11cf-88cb-001111000030}', 'vendor_id': 1133, 'product_id': 50489, 'serial_number': '', 'release_number': 14596, 'manufacturer_string': 'Logitech', 'product_string': 'USB Receiver', 'usage_page': 1, 'usage': 2, 'interface_number': 1}
{'path': b'\\\\?\\HID#VID_046D&PID_C539&MI_01&Col02#8&2bdf73fc&0&0001#{4d1e55b2-f16f-11cf-88cb-001111000030}', 'vendor_id': 1133, 'product_id': 50489, 'serial_number': '', 'release_number': 14596, 'manufacturer_string': 'Logitech', 'product_string': 'USB Receiver', 'usage_page': 12, 'usage': 1, 'interface_number': 1}
{'path': b'\\\\?\\HID#VID_FEED&PID_0000&MI_01&Col03#8&44fbe79&0&0002#{4d1e55b2-f16f-11cf-88cb-001111000030}', 'vendor_id': 65261, 'product_id': 0, 'serial_number': '', 'release_number': 1, 'manufacturer_string': 'Vincent Zhao Zhang', 'product_string': 'zz64', 'usage_page': 12, 'usage': 1, 'interface_number': 1}
{'path': b'\\\\?\\HID#VID_046D&PID_C539&MI_01&Col03#8&2bdf73fc&0&0002#{4d1e55b2-f16f-11cf-88cb-001111000030}', 'vendor_id': 1133, 'product_id': 50489, 'serial_number': '', 'release_number': 14596, 'manufacturer_string': 'Logitech', 'product_string': 'USB Receiver', 'usage_page': 1, 'usage': 128, 'interface_number': 1}
{'path': b'\\\\?\\HID#VID_046D&PID_C539&MI_02&Col01#8&141be7b7&0&0000#{4d1e55b2-f16f-11cf-88cb-001111000030}', 'vendor_id': 1133, 'product_id': 50489, 'serial_number': '', 'release_number': 14596, 'manufacturer_string': 'Logitech', 'product_string': 'USB Receiver', 'usage_page': 65280, 'usage': 1, 'interface_number': 2}
{'path': b'\\\\?\\HID#VID_046D&PID_C539&MI_01&Col04#8&2bdf73fc&0&0003#{4d1e55b2-f16f-11cf-88cb-001111000030}', 'vendor_id': 1133, 'product_id': 50489, 'serial_number': '', 'release_number': 14596, 'manufacturer_string': 'Logitech', 'product_string': 'USB Receiver', 'usage_page': 65468, 'usage': 136, 'interface_number': 1}
{'path': b'\\\\?\\HID#VID_046D&PID_C539&MI_02&Col02#8&141be7b7&0&0001#{4d1e55b2-f16f-11cf-88cb-001111000030}', 'vendor_id': 1133, 'product_id': 50489, 'serial_number': '', 'release_number': 14596, 'manufacturer_string': 'Logitech', 'product_string': 'USB Receiver', 'usage_page': 65280, 'usage': 2, 'interface_number': 2}
{'path': b'\\\\?\\HID#VID_046D&PID_C539&MI_02&Col03#8&141be7b7&0&0002#{4d1e55b2-f16f-11cf-88cb-001111000030}', 'vendor_id': 1133, 'product_id': 50489, 'serial_number': '', 'release_number': 14596, 'manufacturer_string': 'Logitech', 'product_string': 'USB Receiver', 'usage_page': 65280, 'usage': 4, 'interface_number': 2}
Unsupported media type: "{47504A4D-0000-0010-8000-00AA00389B71}"
Unsupported media type: "{47504A4D-0000-0010-8000-00AA00389B71}"
Unsupported media type: "{47504A4D-0000-0010-8000-00AA00389B71}"
Unsupported media type: "{47504A4D-0000-0010-8000-00AA00389B71}"
Unsupported media type: "{47504A4D-0000-0010-8000-00AA00389B71}"
Unsupported media type: "{47504A4D-0000-0010-8000-00AA00389B71}"
Unsupported media type: "{47504A4D-0000-0010-8000-00AA00389B71}"
Unsupported media type: "{47504A4D-0000-0010-8000-00AA00389B71}"
Unsupported media type: "{47504A4D-0000-0010-8000-00AA00389B71}"
Unsupported media type: "{47504A4D-0000-0010-8000-00AA00389B71}"
Unsupported media type: "{47504A4D-0000-0010-8000-00AA00389B71}"
Unsupported media type: "{32595559-0000-0010-8000-00AA00389B71}"
Unsupported media type: "{32595559-0000-0010-8000-00AA00389B71}"
Unsupported media type: "{32595559-0000-0010-8000-00AA00389B71}"
Unsupported media type: "{32595559-0000-0010-8000-00AA00389B71}"
Unsupported media type: "{32595559-0000-0010-8000-00AA00389B71}"
Unsupported media type: "{32595559-0000-0010-8000-00AA00389B71}"
Unsupported media type: "{32595559-0000-0010-8000-00AA00389B71}"
Unsupported media type: "{32595559-0000-0010-8000-00AA00389B71}"
Unsupported media type: "{32595559-0000-0010-8000-00AA00389B71}"
Unsupported media type: "{32595559-0000-0010-8000-00AA00389B71}"
Unsupported media type: "{32595559-0000-0010-8000-00AA00389B71}"
[PyQt5.QtCore.QSize(640, 480), PyQt5.QtCore.QSize(720, 480), PyQt5.QtCore.QSize(720, 576), PyQt5.QtCore.QSize(800, 600), PyQt5.QtCore.QSize(1024, 768), PyQt5.QtCore.QSize(1280, 720), PyQt5.QtCore.QSize(1360, 768), PyQt5.QtCore.QSize(1280, 960), PyQt5.QtCore.QSize(1280, 1024), PyQt5.QtCore.QSize(1600, 1200), PyQt5.QtCore.QSize(1920, 1080)]
1920x1080
< [0, 1, 0, 0, 0, 0, 0, 0, 0, 0, 0]
0
['1920', '1080']
{'connected': False, 'device_No': 0, 'device_name': ['USB Video'], 'resolution_X': 1920, 'resolution_Y': 1080, 'startup_autoConnect': False}
Unsupported media type: "{47504A4D-0000-0010-8000-00AA00389B71}"
Unsupported media type: "{47504A4D-0000-0010-8000-00AA00389B71}"
Unsupported media type: "{47504A4D-0000-0010-8000-00AA00389B71}"
Unsupported media type: "{47504A4D-0000-0010-8000-00AA00389B71}"
Unsupported media type: "{47504A4D-0000-0010-8000-00AA00389B71}"
Unsupported media type: "{47504A4D-0000-0010-8000-00AA00389B71}"
Unsupported media type: "{47504A4D-0000-0010-8000-00AA00389B71}"
Unsupported media type: "{47504A4D-0000-0010-8000-00AA00389B71}"
Unsupported media type: "{47504A4D-0000-0010-8000-00AA00389B71}"
Unsupported media type: "{47504A4D-0000-0010-8000-00AA00389B71}"
Unsupported media type: "{47504A4D-0000-0010-8000-00AA00389B71}"
Unsupported media type: "{32595559-0000-0010-8000-00AA00389B71}"
Unsupported media type: "{32595559-0000-0010-8000-00AA00389B71}"
Unsupported media type: "{32595559-0000-0010-8000-00AA00389B71}"
Unsupported media type: "{32595559-0000-0010-8000-00AA00389B71}"
Unsupported media type: "{32595559-0000-0010-8000-00AA00389B71}"
Unsupported media type: "{32595559-0000-0010-8000-00AA00389B71}"
Unsupported media type: "{32595559-0000-0010-8000-00AA00389B71}"
Unsupported media type: "{32595559-0000-0010-8000-00AA00389B71}"
Unsupported media type: "{32595559-0000-0010-8000-00AA00389B71}"
Unsupported media type: "{32595559-0000-0010-8000-00AA00389B71}"
Unsupported media type: "{32595559-0000-0010-8000-00AA00389B71}"
{'path': b'\\\\?\\HID#VID_046D&PID_C539&MI_00#8&808363a&0&0000#{4d1e55b2-f16f-11cf-88cb-001111000030}\\KBD', 'vendor_id': 1133, 'product_id': 50489, 'serial_number': '', 'release_number': 14596, 'manufacturer_string': 'Logitech', 'product_string': 'USB Receiver', 'usage_page': 1, 'usage': 6, 'interface_number': 0}
{'path': b'\\\\?\\HID#VID_048D&PID_5702&Col01#7&38401973&1&0000#{4d1e55b2-f16f-11cf-88cb-001111000030}', 'vendor_id': 1165, 'product_id': 22274, 'serial_number': '', 'release_number': 1, 'manufacturer_string': 'ITE Tech. Inc.', 'product_string': 'ITE Device', 'usage_page': 65417, 'usage': 16, 'interface_number': -1}
{'path': b'\\\\?\\HID#VID_048D&PID_5702&Col02#7&38401973&1&0001#{4d1e55b2-f16f-11cf-88cb-001111000030}', 'vendor_id': 1165, 'product_id': 22274, 'serial_number': '', 'release_number': 1, 'manufacturer_string': 'ITE Tech. Inc.', 'product_string': 'ITE Device', 'usage_page': 65417, 'usage': 204, 'interface_number': -1}
{'path': b'\\\\?\\HID#VID_FEED&PID_0000&MI_00#8&1c134abe&0&0000#{4d1e55b2-f16f-11cf-88cb-001111000030}\\KBD', 'vendor_id': 65261, 'product_id': 0, 'serial_number': '', 'release_number': 1, 'manufacturer_string': 'Vincent Zhao Zhang', 'product_string': 'zz64', 'usage_page': 1, 'usage': 6, 'interface_number': 0}
{'path': b'\\\\?\\HID#VID_FEED&PID_0000&MI_01&Col01#8&44fbe79&0&0000#{4d1e55b2-f16f-11cf-88cb-001111000030}', 'vendor_id': 65261, 'product_id': 0, 'serial_number': '', 'release_number': 1, 'manufacturer_string': 'Vincent Zhao Zhang', 'product_string': 'zz64', 'usage_page': 1, 'usage': 2, 'interface_number': 1}
{'path': b'\\\\?\\HID#VID_413D&PID_2107#8&2cadb3f0&0&0000#{4d1e55b2-f16f-11cf-88cb-001111000030}', 'vendor_id': 16701, 'product_id': 8455, 'serial_number': '', 'release_number': 256, 'manufacturer_string': 'Moyu at work Technology', 'product_string': 'KVM Card Mini', 'usage_page': 65280, 'usage': 1, 'interface_number': -1}
{'path': b'\\\\?\\HID#VID_FEED&PID_0000&MI_01&Col02#8&44fbe79&0&0001#{4d1e55b2-f16f-11cf-88cb-001111000030}', 'vendor_id': 65261, 'product_id': 0, 'serial_number': '', 'release_number': 1, 'manufacturer_string': 'Vincent Zhao Zhang', 'product_string': 'zz64', 'usage_page': 1, 'usage': 128, 'interface_number': 1}
{'path': b'\\\\?\\HID#VID_534D&PID_2109&MI_04#9&12dff07&0&0000#{4d1e55b2-f16f-11cf-88cb-001111000030}', 'vendor_id': 21325, 'product_id': 8457, 'serial_number': '', 'release_number': 8448, 'manufacturer_string': 'MACROSILICON', 'product_string': 'USB Video', 'usage_page': 65280, 'usage': 1, 'interface_number': 4}
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
Jackadminx, 2024-06-04:
可以尝试其他USB接口，使用虚拟机或者新建分区安装全新系统进行测试排除环境问题。

Jackadminx, 2024-06-04:
有听说AMD芯片的机器会有USB兼容性问题

vincentzz, 2024-06-11:
> 有听说AMD芯片的机器会有USB兼容性问题

果然是这个问题，换成INTEL机器是没问题的。AMD机器，后USB-C不能用，前置USB-A不能用，只有后置USB 3.0工作。。。
找问题找了好久，多谢大佬提示。

Closed 2024-06-11.

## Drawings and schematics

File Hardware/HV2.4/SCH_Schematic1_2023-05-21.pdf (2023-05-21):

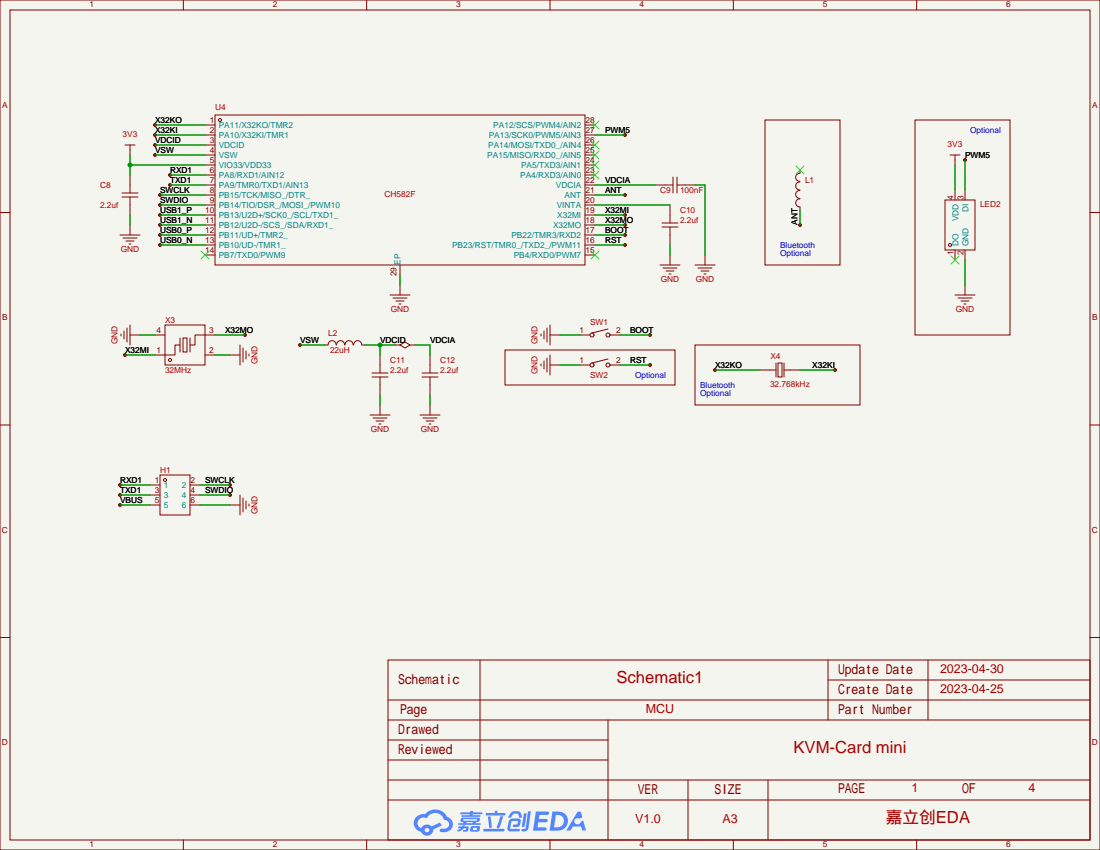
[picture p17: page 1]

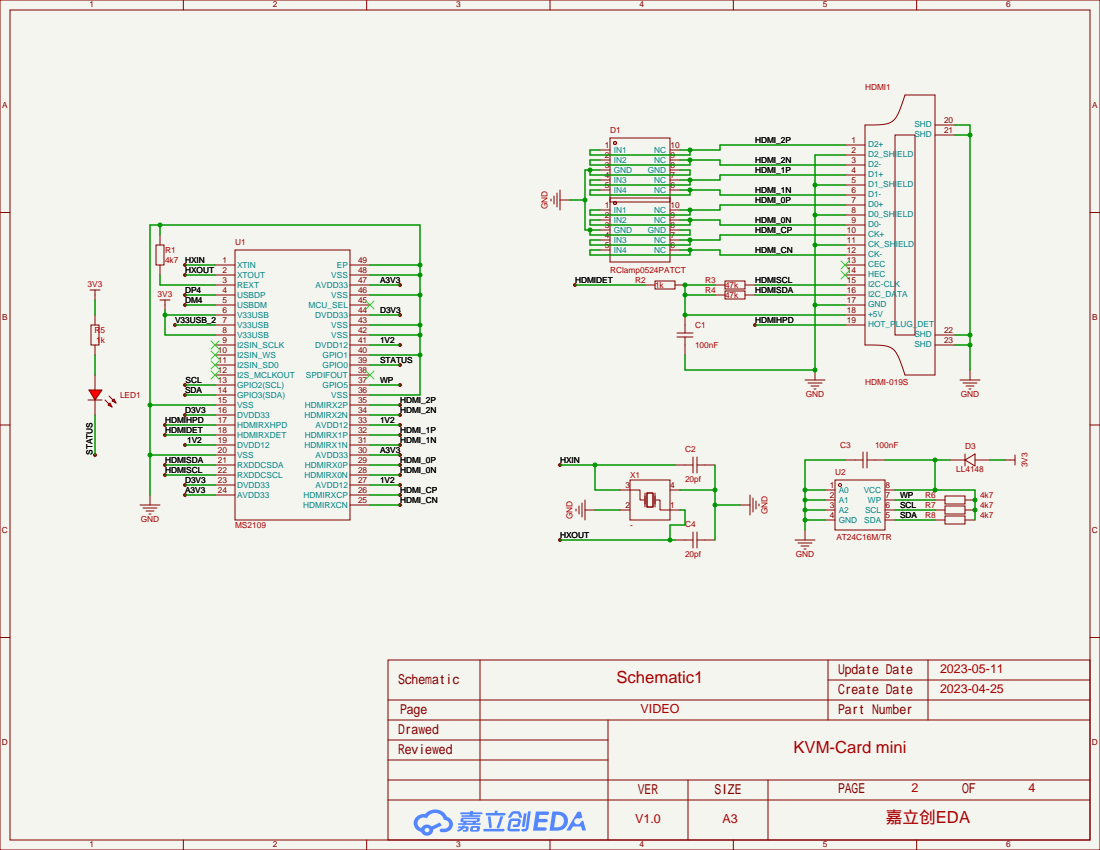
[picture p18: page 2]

Type-C DN | SL2.1A

# Type-C UP

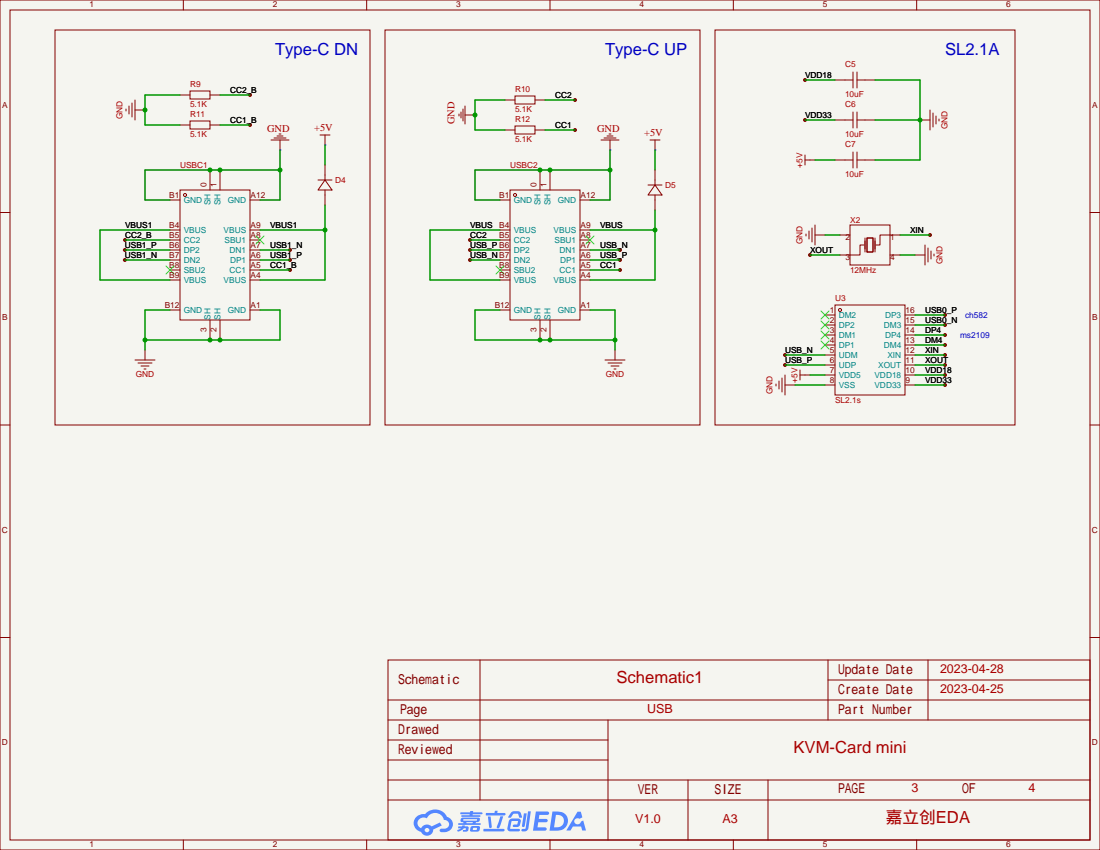
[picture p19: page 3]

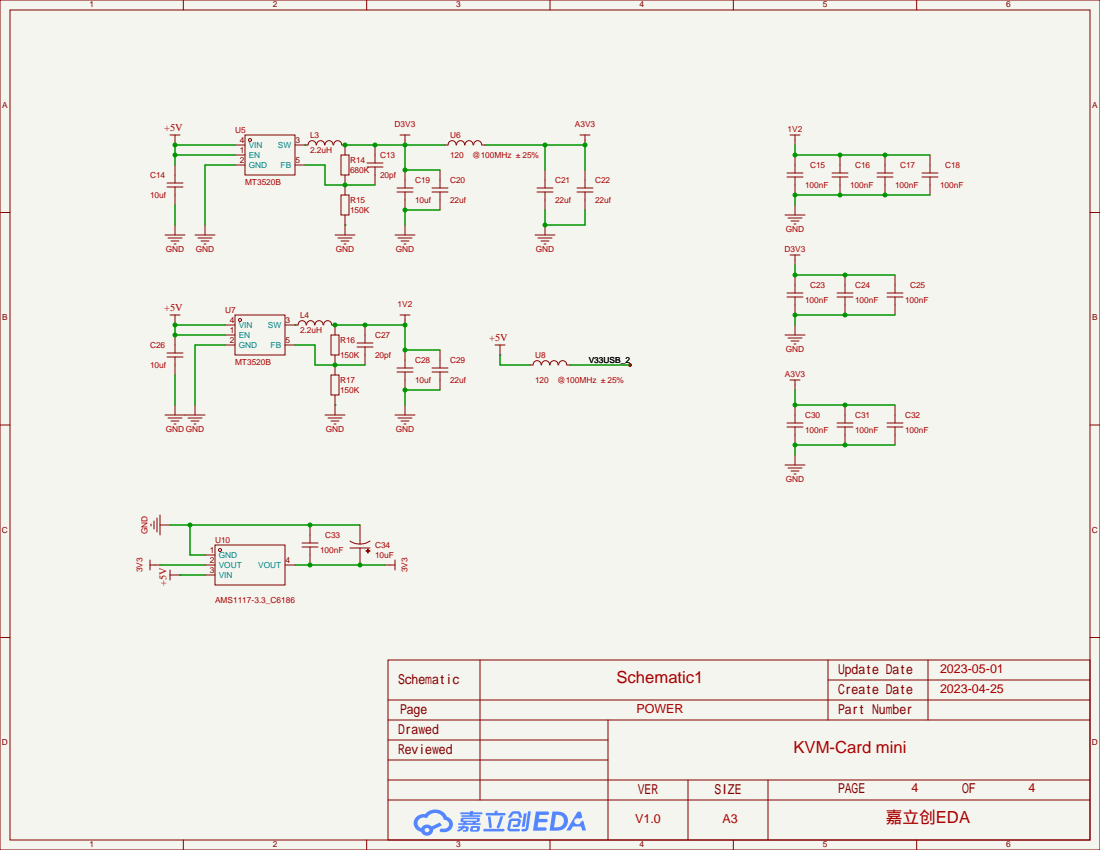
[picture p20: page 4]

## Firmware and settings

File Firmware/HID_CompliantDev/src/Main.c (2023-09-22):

/***************************************************************************** 
 * File Name          : Main.c
 * Author             : Jancgk
 * Version            : V1.1
 * Date               : 2022/01/25
 * Description        : 模拟兼容HID设备
 *********************************************************************************
  * Modified from WCH CH583 source code
 * Copyright (c) 2021 Nanjing Qinheng Microelectronics Co., Ltd.
 * Attention: This software (modified or not) and binary are used for
 * microcontroller manufactured by Nanjing Qinheng Microelectronics.
 *******************************************************************************/

#include "CH58x_common.h"
#include "ws2812b.h"

#define DevEP0SIZE 0x40
uint8_t RGBSET[2] = {0, 0};
// 设备描述符
const uint8_t MyDevDescr[] = {0x12, 0x01, 0x00, 0x02, 0x00, 0x00, 0x00, DevEP0SIZE, 0x3d, 0x41, 0x07, 0x21, 0x00, 0x01, 0x01, 0x02, 0x00, 0x01};
// 配置描述符
const uint8_t MyCfgDescr[] = {
    0x09, 0x02, 0x29, 0x00, 0x01, 0x01, 0x04, 0xA0, 0x64, // 配置描述符
    0x09, 0x04, 0x00, 0x00, 0x02, 0x03, 0x00, 0x00, 0x05, // 接口描述符
    0x09, 0x21, 0x00, 0x01, 0x00, 0x01, 0x22, 0x22, 0x00, // HID类描述符
    0x07, 0x05, 0x81, 0x03, 0x40, 0x00, 0x01,             // 端点描述符
    0x07, 0x05, 0x01, 0x03, 0x40, 0x00, 0x01              // 端点描述符
};
/*字符串描述符略*/
/*HID类报表描述符*/
const uint8_t HIDDescr[] = {0x06, 0x00, 0xff,
                            0x09, 0x01,
                            0xa1, 0x01,       // 集合开始
                            0x09, 0x02,       // Usage Page  用法
                            0x15, 0x00,       // Logical  Minimun
                            0x26, 0x00, 0xff, // Logical  Maximun
                            0x75, 0x08,       // Report Size
                            0x95, 0x0A,       // Report Counet
                            0x81, 0x06,       // Input
                            0x09, 0x02,       // Usage Page  用法
                            0x15, 0x00,       // Logical  Minimun
                            0x26, 0x00, 0xff, // Logical  Maximun
                            0x75, 0x08,       // Report Size
                            0x95, 0x0A,       // Report Counet
                            0x91, 0x06,       // Output
                            0xC0};
// 语言描述符
const uint8_t MyLangDescr[] = {0x04, 0x03, 0x09, 0x04};
// 厂家信息
const uint8_t MyManuInfo[] = {0x30, 0x03, 'M', 0, 'o', 0, 'y', 0, 'u', 0, ' ', 0, 'a', 0, 't', 0, ' ', 0, 'w', 0, 'o', 0, 'r', 0, 'k', 0, ' ', 0, 'T', 0, 'e', 0, 'c', 0, 'h', 0, 'n', 0, 'o', 0, 'l', 0, 'o', 0, 'g', 0, 'y', 0}; // MoYu at work Technology
// 产品信息
const uint8_t MyProdInfo[] = {0x1C, 0x03, 'K', 0, 'V', 0, 'M', 0, ' ', 0, 'C', 0, 'a', 0, 'r', 0, 'd', 0, ' ', 0, 'M', 0, 'i', 0, 'n', 0, 'i', 0};

/**********************************************************/
uint8_t DevConfig, Ready = 0;
uint8_t SetupReqCode;
uint16_t SetupReqLen;
const uint8_t *pDescr;
uint8_t Report_Value = 0x00;
uint8_t Idle_Value = 0x00;
uint8_t USB_SleepStatus = 0x00; /* USB睡眠状态 */

// HID设备中断传输中上传给主机4字节的数据
uint8_t HID_Buf[10] = {0x0};

/*HID上下行数据*/
// uint8_t HIDInData[10] = {0x0};
uint8_t HIDOutData[10] = {0x0};
// uint8_t HIDOutDataTrigger = 0;
uint8_t HIDKeyLightsCode = 0;
// 检查是否支持usb switch
uint8_t USBSwitchSupportStatus = 0;

uint8_t buf[3] = {0};

/******** 用户自定义分配端点RAM ****************************************/
__attribute__((aligned(4))) uint8_t EP0_Databuf[64 + 64 + 64]; // ep0(64)+ep4_out(64)+ep4_in(64)
__attribute__((aligned(4))) uint8_t EP1_Databuf[64 + 64];      // ep1_out(64)+ep1_in(64)
__attribute__((aligned(4))) uint8_t EP2_Databuf[64 + 64];      // ep2_out(64)+ep2_in(64)
__attribute__((aligned(4))) uint8_t EP3_Databuf[64 + 64];      // ep3_out(64)+ep3_in(64)

// USB2
//---------------------------------------------------------------------------------------
//---------------------------------------------------------------------------------------
#define U2DevEP0SIZE 0x40
// 设备描述符
const uint8_t U2MyDevDescr[] =
    {0x12, 0x01, 0x00, 0x02, 0x00, 0x00, 0x00, U2DevEP0SIZE, 0x3d, 0x41,
     0x08, 0x21, 0x00, 0x01, 0x01, 0x02, 0x00, 0x01};
/*HID类报表描述符*/
const uint8_t U2KeyRepDesc[] = {0x05, 0x01, 0x09, 0x06, 0xA1, 0x01, 0x05, 0x07,
                                0x19, 0xe0, 0x29, 0xe7, 0x15, 0x00, 0x25, 0x01, 0x75, 0x01, 0x95, 0x08,
                                0x81, 0x02, 0x95, 0x01, 0x75, 0x08, 0x81, 0x01, 0x95, 0x03, 0x75, 0x01,
                                0x05, 0x08, 0x19, 0x01, 0x29, 0x03, 0x91, 0x02, 0x95, 0x05, 0x75, 0x01,
                                0x91, 0x01, 0x95, 0x06, 0x75, 0x08, 0x26, 0xff, 0x00, 0x05, 0x07, 0x19,
                                0x00, 0x29, 0x91, 0x81, 0x00, 0xC0};
const uint8_t U2MouseRepDesc[] = {
    // Relative
    //   0x05, 0x01, 0x09, 0x02, 0xA1, 0x01, 0x09,
    //   0x01, 0xA1, 0x00, 0x05, 0x09, 0x19, 0x01, 0x29, 0x03, 0x15, 0x00, 0x25,
    //   0x01, 0x75, 0x01, 0x95, 0x03, 0x81, 0x02, 0x75, 0x05, 0x95, 0x01, 0x81,
    //   0x01, 0x05, 0x01, 0x09, 0x30, 0x09, 0x31, 0x09, 0x38, 0x15, 0x81, 0x25,
    //   0x7f, 0x75, 0x08, 0x95, 0x03, 0x81, 0x06, 0xC0, 0xC0

    // Absolute mouse
    0x05, 0x01, // Usage Page (Generic Desktop)
    0x09, 0x02, // Usage (Mouse)
    0xA1, 0x01, // Collection (Application)
    0x09, 0x01, // Usage (Pointer)
    0xA1, 0x00, // Collection (Physical)
    // 0x85, 0x0B,    // Report ID  [11 is SET at RUNTIME]
    // Buttons
    0x05, 0x09, // Usage Page (Button)
    0x19, 0x01, // Usage Minimum (0x01)
    0x29, 0x05, // Usage Maximum (0x05)
    0x15, 0x00, // Logical Minimum (0)
    0x25, 0x01, // Logical Maximum (1)
    0x95, 0x05, // Report Count (5)
    0x75, 0x01, // Report Size (1)
    0x81, 0x02, // Input (Data,Var,Abs,No Wrap,Linear,Preferred State,No Null Position)
    0x75, 0x03, // Report Size (3)
    0x95, 0x01, // Report Count (1)
    0x81, 0x03, // Input (Const,Array,Abs,No Wrap,Linear,Preferred State,No Null Position)
    // Movement
    0x05, 0x01,       // Usage Page (Generic Desktop Ctrls)
    0x09, 0x30,       // Usage (X)
    0x09, 0x31,       // Usage (Y)
    0x15, 0x00,       // LOGICAL_MINIMUM (0)       ; Note: 0x15 = 1 Byte; 0x16 = 2 Byte; 0x17 = 4 Byte
    0x26, 0xFF, 0x7F, // LOGICAL_MAXIMUM (32767)   ; Note: 0x25 = 1 Byte, 0x26 = 2 Byte; 0x27 = 4 Byte Report
    0x35, 0x00,       // Physical Minimum (0)
    0x46, 0xff, 0x7f, // Physical Maximum (32767)
    0x75, 0x10,       // REPORT_SIZE (16)
    0x95, 0x02,       // REPORT_COUNT (2)
    0x81, 0x02,       // Input (Data,Var,Rel,No Wrap,Linear,Preferred State,No Null Position)
    // Wheel
    0x09, 0x38, // Usage (Wheel)
    0x15, 0x81, // Logical Minimum (-127)
    0x25, 0x7F, // Logical Maximum (127)
    0x35, 0x81, // Physical Minimum (same as logical)
    0x45, 0x7f, // Physical Maximum (same as logical)
    0x75, 0x08, // Report Size (8)
    0x95, 0x01, // Report Count (1)
    0x81, 0x06, // Input (Data,Var,Rel,No Wrap,Linear,Preferred State,No Null Position)
    0xC0,       //   End Collection
    0xC0        // End Collection

};
// 配置描述符
const uint8_t U2MyCfgDescr[] = {
    0x09, 0x02, 0x3b, 0x00, 0x02, 0x01, 0x00, 0xE0,
    0x19,                                                 // 配置描述符
    0x09, 0x04, 0x00, 0x00, 0x01, 0x03, 0x01, 0x01, 0x00, // 接口描述符,键盘
    0x09, 0x21, 0x11, 0x01, 0x00, 0x01, 0x22, 0x3e, 0x00, // HID类描述符
    0x07, 0x05, 0x81, 0x03, 0x08, 0x00, 0x0a,             // 端点描述符
    0x09, 0x04, 0x01, 0x00, 0x01, 0x03, 0x01, 0x02, 0x00, // 接口描述符,鼠标
    0x09, 0x21, 0x10, 0x01, 0x00, 0x01, 0x22, sizeof(U2MouseRepDesc) & 0xFF, sizeof(U2MouseRepDesc) >> 8, // HID类描述符
    0x07, 0x05, 0x82, 0x03, 0x06, 0x00, 0x01                                                              // 端点描述符

};
/* USB速度匹配描述符 */
const uint8_t U2My_QueDescr[] = {0x0A, 0x06, 0x00, 0x02, 0xFF, 0x00, 0xFF,
                                 0x40, 0x01, 0x00};

/* USB全速模式,其他速度配置描述符 */
uint8_t U2USB_FS_OSC_DESC[sizeof(U2MyCfgDescr)] = {
    0x09, 0x07, /* 其他部分通过程序复制 */
};

// 产品信息
const uint8_t U2MyProdInfo[] = {0x1E, 0x03, 'K', 0, 'V', 0, 'M', 0, ' ', 0, 'C', 0, 'o', 0, 'n', 0, 't', 0, 'r', 0, 'o', 0, 'l', 0, 'l', 0, 'e', 0, 'd', 0};

/**********************************************************/
uint8_t U2DevConfig, U2Ready;
uint8_t U2SetupReqCode;
uint16_t U2SetupReqLen;
const uint8_t *pU2Descr;
uint8_t U2Report_Value = 0x00;
uint8_t U2Idle_Value = 0x00;
uint8_t U2USB_SleepStatus = 0x00; /* USB睡眠状态 */

/*鼠标键盘数据*/
uint8_t U2HIDMouse[6] = {0x0};
uint8_t U2HIDKey[8] = {0x0};
/******** 用户自定义分配端点RAM ****************************************/
__attribute__((aligned(4))) uint8_t U2EP0_Databuf[64 + 64 + 64]; // ep0(64)+ep4_out(64)+ep4_in(64)
__attribute__((aligned(4))) uint8_t U2EP1_Databuf[64 + 64];      // ep1_out(64)+ep1_in(64)
__attribute__((aligned(4))) uint8_t U2EP2_Databuf[64 + 64];      // ep2_out(64)+ep2_in(64)
__attribute__((aligned(4))) uint8_t U2EP3_Databuf[64 + 64];      // ep3_out(64)+ep3_in(64)

/*********************************************************************
 * @fn      USB_DevTransProcess
 *
 * @brief   USB 传输处理函数
 *
 * @return  none
 */
void USB_DevTransProcess(void) // USB设备传输中断处理
{
    uint8_t len, chtype;          // len用于拷贝函数，chtype用于存放数据传输方向、命令的类型、接收的对象等信息
    uint8_t intflag, errflag = 0; // intflag用于存放标志寄存器值，errflag用于标记是否支持主机的指令

    intflag = R8_USB_INT_FG; // 取得中断标识寄存器的值

    if (intflag & RB_UIF_TRANSFER) // 判断_INT_FG中的USB传输完成中断标志位。若有传输完成中断了，进if语句
    {
        if ((R8_USB_INT_ST & MASK_UIS_TOKEN) != MASK_UIS_TOKEN) // 非空闲   //判断中断状态寄存器中的5:4位，查看令牌的PID标识。若这两位不是11（表示空闲），进if语句
        {
            switch (R8_USB_INT_ST & (MASK_UIS_TOKEN | MASK_UIS_ENDP)) // 取得令牌的PID标识和设备模式下的3:0位的端点号。主机模式下3:0位是应答PID标识位
            // 分析操作令牌和端点号
            {                         // 端点0用于控制传输。以下的端点0的IN和OUT令牌相应程序，对应控制传输的数据阶段和状态阶段。
            case UIS_TOKEN_IN:        // 令牌包的PID为IN，5:4位为10。3:0位的端点号为0。IN令牌：设备给主机发数据。_UIS_：USB中断状态
            {                         // 端点0为双向端点，用作控制传输。 “|0”运算省略了
                switch (SetupReqCode) // 这个值会在收到SETUP包时赋值。在后面会有SETUP包处理程序，对应控制传输的设置阶段。
                {
                case USB_GET_DESCRIPTOR:                                        // USB标准命令，主机从USB设备获取描述
                    len = SetupReqLen >= DevEP0SIZE ? DevEP0SIZE : SetupReqLen; // 本次包传输长度。最长为64字节，超过64字节的分多次处理，前几次要满包。
                    memcpy(pEP0_DataBuf, pDescr, len);                          // memcpy:内存拷贝函数，从(二号位)地址拷贝(三号位)字符串长度到(一号位)地址中
                    // DMA直接与内存相连，会检测到内存的改写，而后不用单片机控制就可以将内存中的数据发送出去。如果只是两个数组互相赋值，不涉及与DMA匹配的物理内存，就无法触发DMA。
                    SetupReqLen -= len;           // 记录剩下的需要发送的数据长度
                    pDescr += len;                // 更新接下来需要发送的数据的起始地址,拷贝函数用
                    R8_UEP0_T_LEN = len;          // 端点0发送长度寄存器中写入本次包传输长度
                    R8_UEP0_CTRL ^= RB_UEP_T_TOG; // 同步切换。IN方向（对于单片机就是T方向）的PID中的DATA0和DATA1切换
                    break;                        // 赋值完端点控制寄存器的握手包响应（ACK、NAK、STALL），由硬件打包成符合规范的包，DMA自动发送
                case USB_SET_ADDRESS:             // USB标准命令，主机为设备设置一个唯一地址，范围0～127，0为默认地址
                    R8_USB_DEV_AD = (R8_USB_DEV_AD & RB_UDA_GP_BIT) | SetupReqLen;
                    // 7位地址+最高位的用户自定义地址（默认为1），或上“包传输长度”（这里的“包传输长度”在后面赋值成了地址位）
                    R8_UEP0_CTRL = UEP_R_RES_ACK | UEP_T_RES_NAK;
                    // R响应OUT事务ACK，T响应IN事务NAK。这个CASE分支里是IN方向，当DMA相应内存中，单片机没有数据更新时，回NAK握手包。
                    break; // 一般程序里的OUT事务，设备会回包给主机，不响应NAK。

                case USB_SET_FEATURE: // USB标准命令，主机要求启动一个在设备、接口或端点上的特征
                    break;

                default:
                    R8_UEP0_T_LEN = 0; // 状态阶段完成中断或者是强制上传0长度数据包结束控制传输（数据字段长度为0的数据包，包里SYNC、PID、EOP字段都有）
                    R8_UEP0_CTRL = UEP_R_RES_ACK | UEP_T_RES_NAK;
                    // R响应OUT事务ACK，T响应IN事务NAK。这个CASE分支里是OUT方向，当DMA相应内存中更新了数据且单片机验收正常时，回ACK握手包。
                    Ready = 1;
                    printf("Ready_STATUS = %d\n", Ready);
                    break;
                }
            }
            break;

            case UIS_TOKEN_OUT:      // 令牌包的PID为OUT，5:4位为00。3:0位的端点号为0。OUT令牌：主机给设备发数据。
            {                        // 端点0为双向端点，用作控制传输。 “|0”运算省略了
                len = R8_USB_RX_LEN; // 读取当前USB接收长度寄存器中存储的接收的数据字节数 //接收长度寄存器为各个端点共用，发送长度寄存器各有各的
            }
            break;

            case UIS_TOKEN_OUT | 1: // 令牌包的PID为OUT，端点号为1
            {
                if (R8_USB_INT_ST & RB_UIS_TOG_OK) // 硬件会判断是否正确的同步切换数据包，同步切换正确，这一位自动置位
                {                                  // 不同步的数据包将丢弃
                    R8_UEP1_CTRL ^= RB_UEP_R_TOG;  // OUT事务的DATA同步切换。设定一个期望值。
                    len = R8_USB_RX_LEN;           // 读取接收数据的字节数
                    DevEP1_OUT_Deal(len);          // 发送长度为len的字节，自动回ACK握手包。自定义的程序。
                }
            }
            break;

            case UIS_TOKEN_IN | 1:                                               // 令牌包的PID为IN，端点号为1
                R8_UEP1_CTRL ^= RB_UEP_T_TOG;                                    // IN事务的DATA切换一下。设定将要发送的包的PID。
                R8_UEP1_CTRL = (R8_UEP1_CTRL & ~MASK_UEP_T_RES) | UEP_T_RES_NAK; // 当DMA中没有由单片机更新数据时，将T响应IN事务置为NAK。更新了就发出数据。
                Ready = 1;
                printf("Ready_IN_EP1 = %d\n", Ready);
                break;
            }
            R8_USB_INT_FG = RB_UIF_TRANSFER; // 写1清零中断标志
        }

        if (R8_USB_INT_ST & RB_UIS_SETUP_ACT) // Setup包处理
        {
            R8_UEP0_CTRL = RB_UEP_R_TOG | RB_UEP_T_TOG | UEP_R_RES_ACK | UEP_T_RES_NAK;
            // R响应OUT事务期待为DATA1（DMA收到的数据包的PID要为DATA1，否则算数据错误要重传）和ACK（DMA相应内存中收到了数据，单片机验收正常）
            // T响应IN事务设定为DATA1（单片机有数据送入DMA相应内存，以DATA1发送出去）和NAK（单片机没有准备好数据）。
            SetupReqLen = pSetupReqPak->wLength;   // 数据阶段的字节数      //pSetupReqPak：将端点0的RAM地址强制转换成一个存放结构体的地址，结构体成员依次紧凑排列
            SetupReqCode = pSetupReqPak->bRequest; // 命令的序号
            chtype = pSetupReqPak->bRequestType;   // 包含数据传输方向、命令的类型、接收的对象等信息

            len = 0;
            errflag = 0;
            if ((pSetupReqPak->bRequestType & USB_REQ_TYP_MASK) != USB_REQ_TYP_STANDARD) // 判断命令的类型，如果不是标准请求，进if语句
            {
                /* 非标准请求 */
                /* 其它请求,如类请求，产商请求等 */
                if (pSetupReqPak->bRequestType & 0x40) // 取得命令中的某一位，判断是否为0，不为零进if语句
                {
                    /* 厂商请求 */
                }
                else if (pSetupReqPak->bRequestType & 0x20) // 取得命令中的某一位，判断是否为0，不为零进if语句
                {                                           // 判断为HID类请求
                    switch (SetupReqCode)                   // 判断命令的序号
                    {
                    case DEF_USB_SET_IDLE: /* 0x0A: SET_IDLE */ // 主机想设置HID设备特定输入报表的空闲时间间隔
                        Idle_Value = EP0_Databuf[3];
                        break; // 这个一定要有

                    case DEF_USB_SET_REPORT: /* 0x09: SET_REPORT */ // 主机想设置HID设备的报表描述符
                        break;

                    case DEF_USB_SET_PROTOCOL: /* 0x0B: SET_PROTOCOL */ // 主机想设置HID设备当前所使用的协议
                        Report_Value = EP0_Databuf[2];
                        break;

                    case DEF_USB_GET_IDLE: /* 0x02: GET_IDLE */ // 主机想读取HID设备特定输入报表的当前的空闲比率
                        EP0_Databuf[0] = Idle_Value;
                        len = 1;
                        break;

                    case DEF_USB_GET_PROTOCOL: /* 0x03: GET_PROTOCOL */ // 主机想获得HID设备当前所使用的协议
                        EP0_Databuf[0] = Report_Value;
                        len = 1;
                        break;

                    default:
                        errflag = 0xFF;
                    }
                }
            }
            else // 判断为标准请求
            {
                switch (SetupReqCode) // 判断命令的序号
                {
                case USB_GET_DESCRIPTOR: // 主机想获得标准描述符
                {
                    switch (((pSetupReqPak->wValue) >> 8)) // 右移8位，看原来的高8位是否为0，为1表示方向为IN方向，则进s-case语句
                    {
                    case USB_DESCR_TYP_DEVICE: // 不同的值代表不同的命令。主机想获得设备描述符
                    {
                        pDescr = MyDevDescr; // 将设备描述符字符串放在pDescr地址中，“获得标准描述符”这个case末尾会用拷贝函数发送
                        len = MyDevDescr[0]; // 协议规定设备描述符的首字节存放字节数长度。拷贝函数会用到len参数
                    }
                    break;

                    case USB_DESCR_TYP_CONFIG: // 主机想获得配置描述符
                    {
                        pDescr = MyCfgDescr; // 将配置描述符字符串放在pDescr地址中，之后会发送
                        len = MyCfgDescr[2]; // 协议规定配置描述符的第三个字节存放配置信息的总长
                    }
                    break;
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
int main()
{
    uint8_t s;
    SetSysClock(CLK_SOURCE_PLL_60MHz);
    DebugInit(); // 配置串口1用来prinft来debug
    printf("start\n");

    /* 配置USB Switch GPIO */

    USBSwitchSupportStatus = GPIOB_ReadPortPin(GPIO_Pin_4) ? 1 : 0;

    GPIOB_ModeCfg(GPIO_Pin_4, GPIO_ModeOut_PP_20mA); // NMOS
    GPIOB_ModeCfg(GPIO_Pin_7, GPIO_ModeOut_PP_5mA);  // IN
    GPIOA_ModeCfg(GPIO_Pin_12, GPIO_ModeOut_PP_5mA); // EN#
    //切换至上位机端，电源接通
    GPIOB_SetBits(GPIO_Pin_4); // pull down
    GPIOB_ResetBits(GPIO_Pin_7);
    GPIOA_ResetBits(GPIO_Pin_12);

    /* 配置WS2812B GPIO */
    GPIOA_ModeCfg(GPIO_Pin_13, GPIO_ModeOut_PP_5mA);
    printf("RGB ON\n");
    // GRB WS2812B
    buf[0] = 0x00;
    buf[1] = 0x05;
    buf[2] = 0x00;
    SendOnePix(buf);

    mDelaymS(100);

    pEP0_RAM_Addr = EP0_Databuf; // 配置缓存区64字节。
    pEP1_RAM_Addr = EP1_Databuf;
    pU2EP0_RAM_Addr = U2EP0_Databuf;
    pU2EP1_RAM_Addr = U2EP1_Databuf;
    pU2EP2_RAM_Addr = U2EP2_Databuf;
    pU2EP3_RAM_Addr = U2EP3_Databuf;

    USB_DeviceInit();
    USB2_DeviceInit();

    PFIC_EnableIRQ(USB_IRQn); // 启用中断向量
    PFIC_EnableIRQ(USB2_IRQn);

    uint8_t i;
    while (1)
    {
        mDelayuS(1000);
    }
}

/*********************************************************************
 * @fn      DevEP1_OUT_Deal
 *
 * @brief   端点1数据处理，收到数据后取反再发出去。用户自行更改。
 *
 * @return  none
 */
void DevEP1_OUT_Deal(uint8_t l)
{ /* 用户可自定义 */

    uint8_t i;

    memcpy(HIDOutData, pEP1_OUT_DataBuf, 10);

    if (HIDOutData[0] == 1)
    {

        memcpy(pU2EP1_IN_DataBuf, HIDOutData + 2, 8);
        U2DevEP1_IN_Deal(8);

    }

    else if (HIDOutData[0] == 2)
    {
        memcpy(pU2EP2_IN_DataBuf, HIDOutData + 2, 6);
        U2DevEP2_IN_Deal(6);
    }

    else if (HIDOutData[0] == 3)
    {
        printf("HIDKeyLightsCode: ");
        HID_Buf[0] = 3;
        HID_Buf[2] = HIDKeyLightsCode;
        DevHIDReport();
    }
    else if (HIDOutData[0] == 4)
    {
        printf("SYS_ResetExecute: ");
        SYS_ResetExecute();
    }

    else if (HIDOutData[0] == 5)
    {
        printf("SET WS2812B: ");
        // GRB
        buf[0] = HIDOutData[2];
        buf[1] = HIDOutData[3];
        buf[2] = HIDOutData[4];
        SendOnePix(buf);
    }
    else if (HIDOutData[0] == 6)
    {
        printf("USB SWITCH: ");
        if (HIDOutData[2] == 0) // 信号线悬空，电源断电
        {
            GPIOB_ResetBits(GPIO_Pin_4); // pull up
            GPIOB_SetBits(GPIO_Pin_7);
            GPIOA_SetBits(GPIO_Pin_12);
            printf("0");
        }
        else if (HIDOutData[2] == 1) // 切换至上位机端，电源接通
        {
            GPIOB_SetBits(GPIO_Pin_4); // pull down
            GPIOB_ResetBits(GPIO_Pin_7);
            GPIOA_ResetBits(GPIO_Pin_12);
            printf("1");
        }
        else if (HIDOutData[2] == 2) // 切换至被控端，电源接通
        {
            GPIOB_SetBits(GPIO_Pin_4); // pull down
            GPIOB_SetBits(GPIO_Pin_7);
            GPIOA_ResetBits(GPIO_Pin_12);
            printf("2");
        }
        else if (HIDOutData[2] == 3) // 状态查询
        {
            HID_Buf[0] = 6;
            HID_Buf[2] = 3;
            HID_Buf[3] = GPIOB_ReadPortPin(GPIO_Pin_4) ? 1 : 0;  // nmos
            HID_Buf[4] = GPIOB_ReadPortPin(GPIO_Pin_7) ? 1 : 0;  // IN
            HID_Buf[5] = GPIOA_ReadPortPin(GPIO_Pin_12) ? 1 : 0; // EN#
            HID_Buf[6] = USBSwitchSupportStatus;
            DevHIDReport();
            printf("3");
        }

        printf("\r\n");
    }
}

/*********************************************************************
 * @fn      USB_IRQHandler
 *
 * @brief   USB中断函数
 *
 * @return  none
 */
__attribute__((interrupt("WCH-Interrupt-fast")))
__attribute__((section(".highcode"))) void
USB_IRQHandler(void) /* USB中断服务程序,使用寄存器组1 */
{
    USB_DevTransProcess();
}

/*********************************************************************
 * @fn      U2DevEP1_OUT_Deal
 *
 * @brief   端点1数据处理
 *
 * @return  none
 */
void U2DevEP1_OUT_Deal(uint8_t l)
{ /* 用户可自定义 */
    uint8_t i;

    for (i = 0; i < l; i++)
    {
        pU2EP1_IN_DataBuf[i] = ~pU2EP1_OUT_DataBuf[i];
    }
    U2DevEP1_IN_Deal(l);
}

/*********************************************************************
 * @fn      U2DevEP2_OUT_Deal
 *
 * @brief   端点2数据处理
 *
 * @return  none
 */
void U2DevEP2_OUT_Deal(uint8_t l)
{ /* 用户可自定义 */
    uint8_t i;

    for (i = 0; i < l; i++)
    {
        pU2EP2_IN_DataBuf[i] = ~pU2EP2_OUT_DataBuf[i];
    }
    U2DevEP2_IN_Deal(l);
}

/*********************************************************************
 * @fn      U2DevEP3_OUT_Deal
 *
 * @brief   端点3数据处理
 *
 * @return  none
 */
void U2DevEP3_OUT_Deal(uint8_t l)
{ /* 用户可自定义 */
    uint8_t i;

    for (i = 0; i < l; i++)
    {
        pU2EP3_IN_DataBuf[i] = ~pU2EP3_OUT_DataBuf[i];
    }
    U2DevEP3_IN_Deal(l);
}

/*********************************************************************
 * @fn      U2DevEP4_OUT_Deal
 *
 * @brief   端点4数据处理
 *
 * @return  none
 */
void U2DevEP4_OUT_Deal(uint8_t l)
{ /* 用户可自定义 */
    uint8_t i;

    for (i = 0; i < l; i++)
    {
        pU2EP4_IN_DataBuf[i] = ~pU2EP4_OUT_DataBuf[i];
    }
    U2DevEP4_IN_Deal(l);
}

/*********************************************************************
 * @fn      USB2_IRQHandler
 *
 * @brief   USB2中断函数
 *
 * @return  none
 */
__INTERRUPT
__HIGH_CODE
void USB2_IRQHandler(void) /* USB中断服务程序,使用寄存器组1 */
{
    USB2_DevTransProcess();
}

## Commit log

2023-05-13 首次上传
    上位机和mcu完整源码
2023-05-14 一些更新
2023-05-21 更新文档
2023-07-22 添加剪切板、截图功能、修复Liunx系统鼠标滚动问题、键盘全键无冲突
2023-07-22 更新图片
2023-09-18 HV2.6支持
2024-12-02 update readme and change dir name
    [BOM_Board1_Schematic1_2023-05-21.xlsx, Shell_Down_HV2.4.stl, Shell_Up_HV2.4.stl]
